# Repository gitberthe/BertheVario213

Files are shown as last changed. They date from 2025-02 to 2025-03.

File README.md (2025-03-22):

# Projet BertheVario213

Projet d'alti vario gps parapente (avec gestion des TMA CTR..., et mode guidage sol pour randonnée).
- Compatible bluetooth / XCTrack si nécessaire.
- Code C++ Visual Studio/PlateformIO.
- Plateforme Espressif ESP32 Dev Module, LILYGO T5 v2.3.1 GDEM0213T5BN 9102 chip, écran 2.13inch DEPG0213BN, Arduino (processeur 32bits, dual core, 240Mhz).

**La carte avec son pcb :**

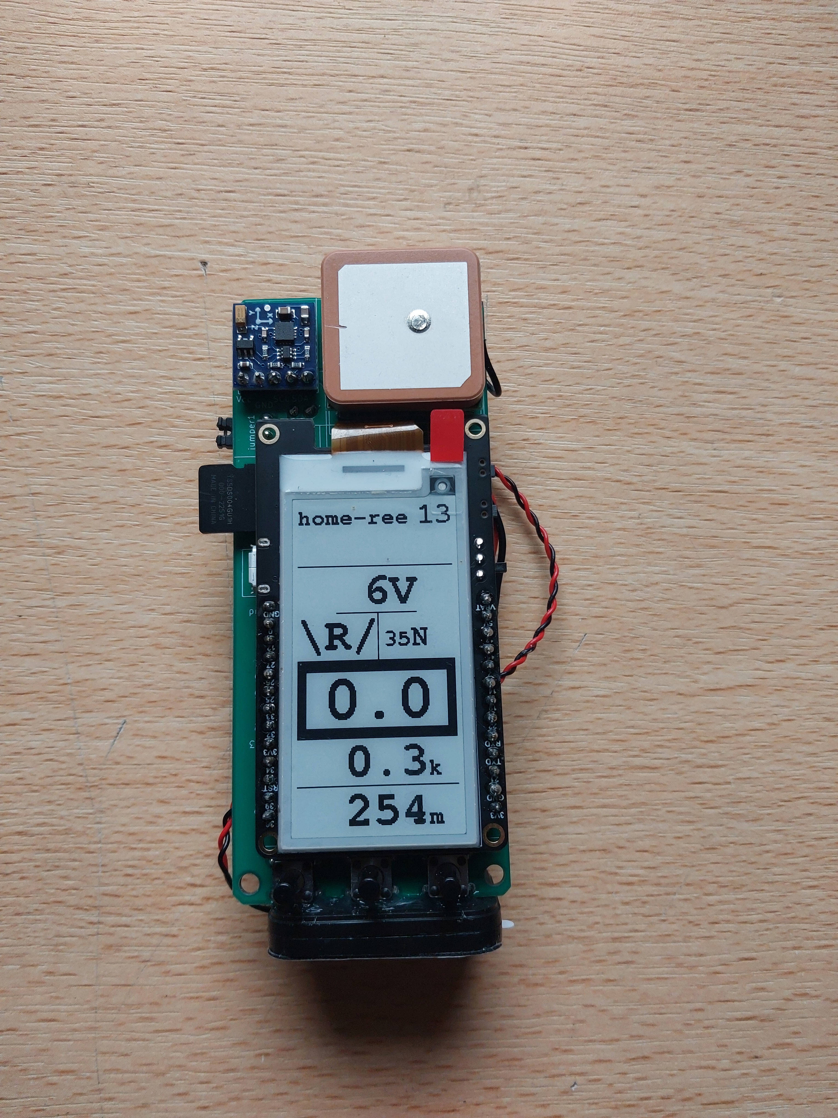
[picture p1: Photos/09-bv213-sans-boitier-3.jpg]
  

**Le schema electrique :**

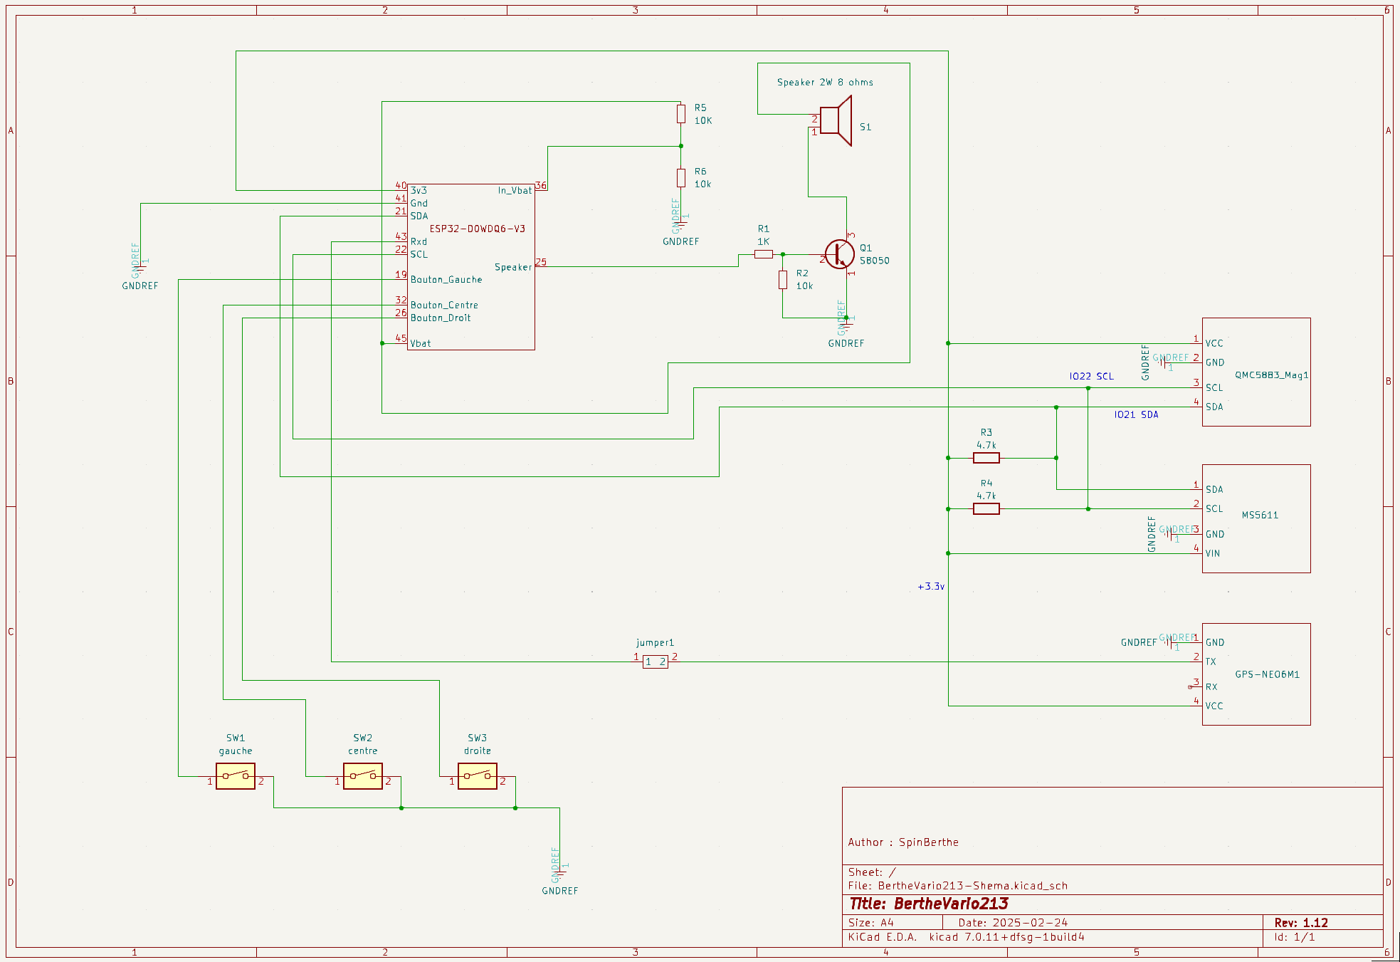
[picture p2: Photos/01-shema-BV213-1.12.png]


**Le pcb :**

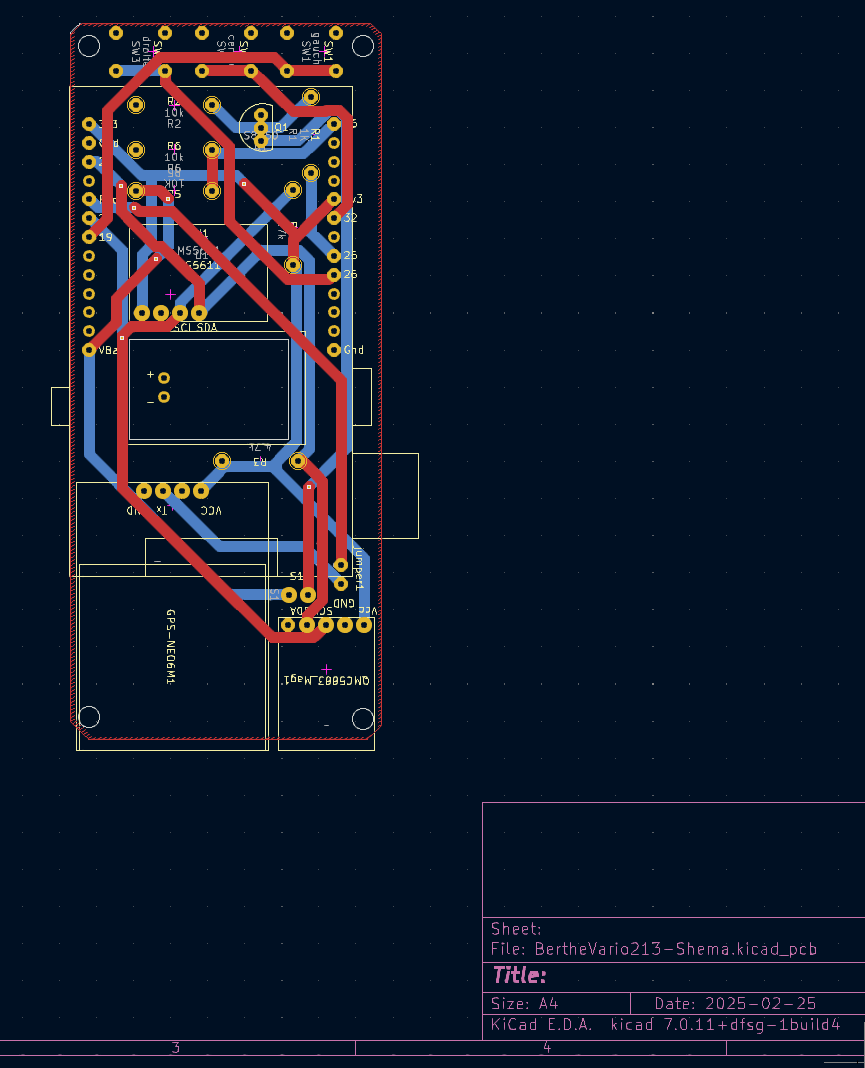
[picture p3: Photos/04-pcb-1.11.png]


**Le mode randonnée :**

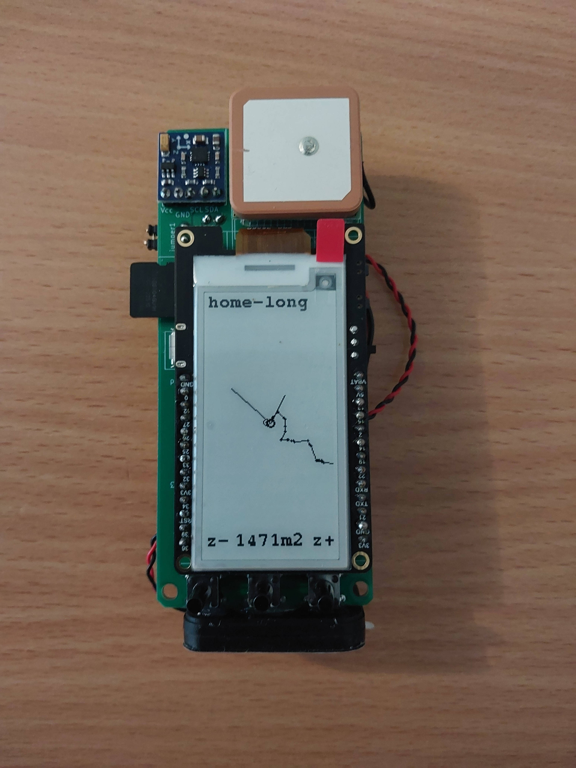
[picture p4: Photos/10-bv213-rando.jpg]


mail: spinberthe@gmail.com

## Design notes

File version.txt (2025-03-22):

le 20250322b :
 - affichage altitude restante/distance/cap de la zone aerienne proche ok.
 - ihm mode randonnee ok.

le 20250322a :
 - emmission message xc_track determiné uniquement par #define XC_TRACK 
 - son vario toujours determiné par [xc_track] == 0 
 - declenchement debut de vol par 2 Vz minimales consecutives. 
 - prise en compte de la hauteur sol pour pre-alarme frontiere XY à Saint-Sandoux.
 - meilleur prise en compte zone st-yan
 - ajout du projet CompZoneAerienne
  
le 20250321c :
 - recadrage caracteres toutes pages.
 
le 20250321b :
 - recadrage caracteres page Sys.

le 20250321a :
 - recadrage caracteres page Vz.

le 20250320d :
 - correction bug bloquage mode ota (firmware wifi).
 - a faire recadrage des caracteres dans les pages.

le 20250320c :
 - quelques modifications de documentation.

le 20250320b :
 - correction bug cap magnetique.
 - ajout vitesse/cap trame RMC Gps (si vitesse faible)

le 20250320a :
 - mode ota ok (firmware wifi).
 - bug cap/vitesse gps trame VTG manquante.
 - bug cap magnetique

le 20250319a :
 - pcb ok. reste a faire le boitier et la mise au point logicielle.

le 20250225c :
 - modif plantage si mauvais zonesper.txt.

le 20250225b :
 - bug periode zone st-yan.

le 20250225a2 :
 - pcb en production mais pas testé.

le 20250225a :
 - modif pcb

le 20250224b :
 - init variables comme vitesse sol gps.
 
le 20250224a :
 - pcb ok a verifier. 

le 20250223a :
 - correction alti baro filtrée.

le 20250222a :
 - mise a jour pcb.
 
le 20250221b :
 - taille caracteres pages.
 
le 20250221a :
 - mise a jour schema/pcb.

le 20250217a4 :
 - modification documentation concepteur.
 - modification pcb

le 20250217a3 :
 - modification pcb.

le 20250217a2 :
 - correction type d'ecran dans documentation.

le 20250217a :
 - progression firmware.

le 20250216a :
 - progression pcb.
 - mise au point son.
 - lecture vbat.

le 20250215a2 :
 - debut conception pcb.

le 20250215a :
 - ajout schema FreeCad et Kicad.
  - rotation ecran.
  
le 20250214b :
 - altitude en bas page Vz.

le 20250214a :
 - ajustement page Vz.

le 20250213c :
 - taille ecran

le 20250213b :
 - reorganisation code

le 20250213a :
 - reception de la lilygo T5 v2.3.1 GDEM0213T5BN 9102 chip, ecran DEPG0213BN :
  . test ecran ok.
  . test carte SD ok.
  . test wifi ok.
  . test ble ok.
 - reste plus qu'a faire tout le reste... gps, boutons, capteur pression, cap magnetique, 
   alimentation, pcb, boitier.
 - l'ecran est tres propre et assez rapide 1/2 image/s.
  
le 20250206a :
 - definition materielle d'un BertheVario ecran 2.13 pouces en cours.

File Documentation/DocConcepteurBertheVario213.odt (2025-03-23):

Documentation Concepteur BertheVario213

Projet d’alti vario gps parapente

à base de

LILYGO T5 v2.3.1 DEPG0213BN 9102 chip

Version 20250322b2

https://github.com/gitberthe/BertheVario213

Compilé avec Visual Studio Code / PlatformIO

Espressif Systems

ESP32 Dev Module

ESP32-D0WDQ6-V3

écran 2.13inch DEPG0213BN

Arduino

langage C++.

spinberthe@gmail.com

# Mise en place de l’environnement logiciel :

Le logiciel est compilé avec Visual Studio Code / PlatformIO.

* La librairie pour le gestionnaire de fichier Wifi doit être modifiée si la version est trop vieille.

Dans BertheVarioTacPlatformIO/.pio/libdeps/esp32dev/ESP32 File Manager for Generation Klick ESPFMfGK/src/ESPFMfGKGa.cpp" ligne 6 : crc32.h => CRC32.h

La compilation du logiciel peut alors s’effectuer.

# Compatibilité XC-Track :

Pour la compilation pour XC-Track voir BertheVarioTac.h et #define XC_TRACK. Ce define consomme de la mémoire. Donc si inutile ne pas le positionner.

Pour supprimer le son du vario, mettre à 0 la variable [xc_track] dans le fichier de configuration (avec le mini éditeur interne).

# Connexion de la batterie :

Connecter la batterie à la carte ESP32 à l’aide du connecteur fournit. Une batterie 4,2v 1S lipo 2000 mah 103450 est suffisante. Elle se recharge par le connecteur usb.

# haut parleur :

Le haut parleur est un haut parleur 2W 8 ohms.

# Téléchargement du firmware :

Pour télécharger le firmware il y a 2 façons :

- soit par câble usb avec platformio ou un autre logiciel. Il faut impérativement retirer le cavalier de la donnée gps pour que le téléchargement se face.

- soit par wifi. Il faut alors mettre le vario en mode téléchargement firmware : page sys, bouton droit long puis gauche court. Et dé-commenter dans platformio.ini les lignes :

; extra_scripts = platformio_upload.py

; upload_protocol = custom

; upload_url = http://192.168.148.237

Avec bien sur l’adresse ip de l’url donnée par l’écran du BertheVario213. Cette procédure ne peut toutefois pas être faite au premier téléchargement de la carte ESP-32. Le logiciel ne s’y trouvant pas, il faut appliquer la procédure USB.

# Quelques photos :

La carte de base ESP32 LILYGO T5 v2.3.1 GDEM0213T5BN 9102 chip avec son écran 2,13 inch DEPG0213BN:

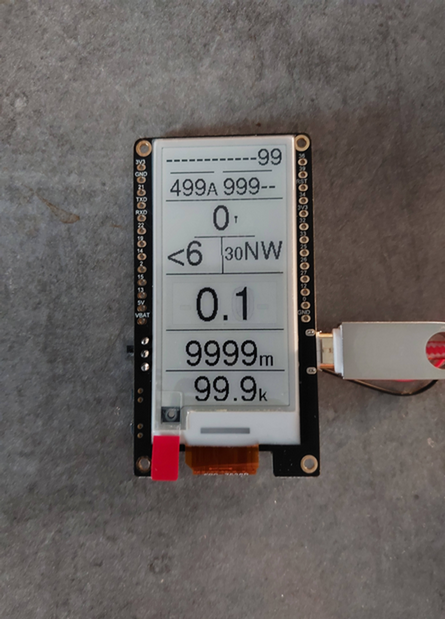
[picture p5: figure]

Attention : Prévoir un film filtre uv car il ne résiste pas au soleil cet écran.

Le circuit imprimé avec ses composants sur les 2 faces. Attention au sens du gps, capteur magnétique, barométrique, et transistor.

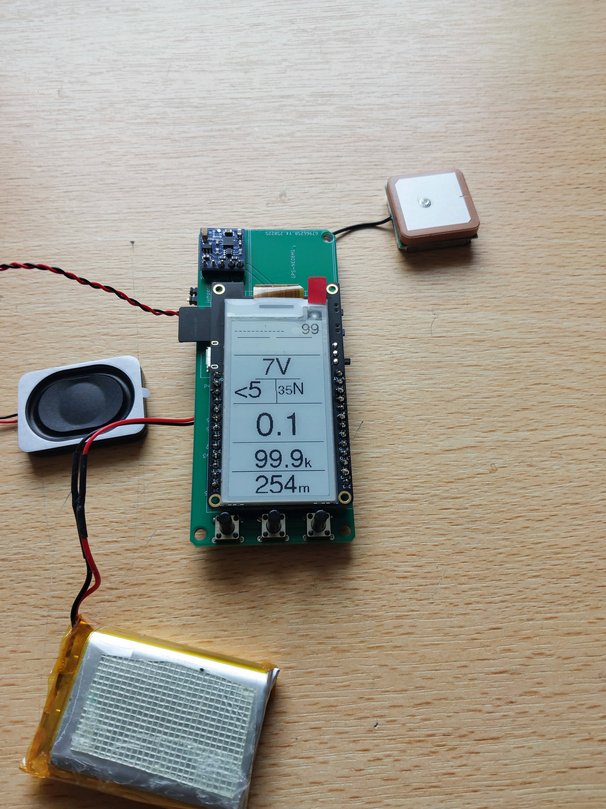
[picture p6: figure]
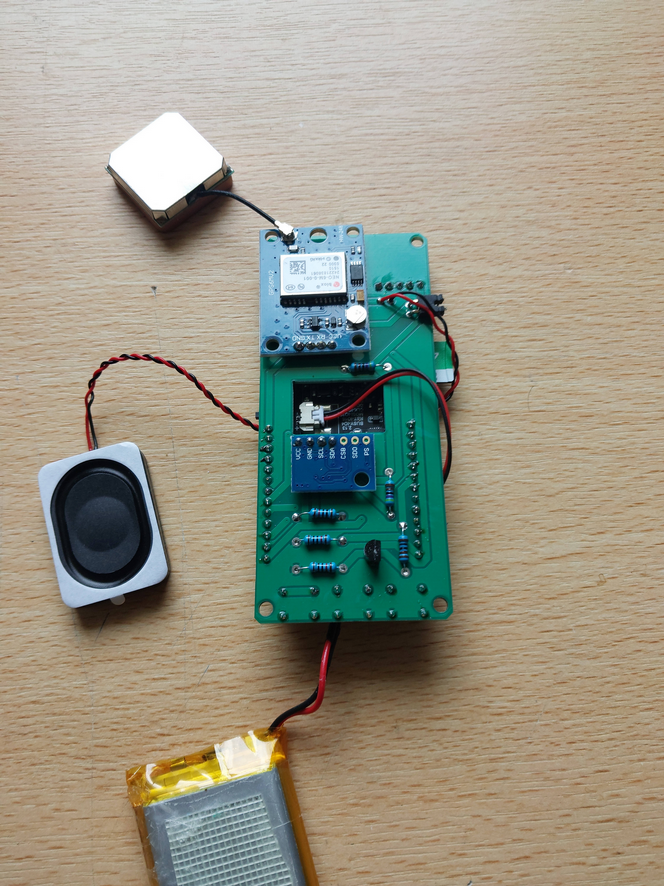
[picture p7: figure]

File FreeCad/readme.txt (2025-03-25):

le 20250325a :
 - conception de boitier en cours.

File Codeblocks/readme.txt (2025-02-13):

- Ce repertoire est present uniquement pour editer/modifier les sources sous codeblocks
- utilisation aussi pour generer la documentation code dans ../../DoxyBertheVario213 : doxygen Doxyfile.BertheVario

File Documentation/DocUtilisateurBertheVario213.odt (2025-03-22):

Documentation Utilisateur BertheVario213

Projet d’alti vario gps parapente

à base de

LILYGO T5 v2.3.1 DEPG0213BN 9102 chip

Version 20250322a

https://github.com/gitberthe/BertheVario213

Compilé avec Visual Studio Code / PlatformIO

Espressif Systems

ESP32 Dev Module

ESP32-D0WDQ6-V3

écran 2.13inch DEPG0213BN

Arduino

langage C++.

spinberthe@gmail.com

Modifications apportées à la documentation :

20250322a: Création documentation utilisateur d’après BertheVario.

# Écran de boot :

A l’écran de boot, il y a possibilité de changer de mode (voir boutons plus bas). Puis il y a affichage de la tension de batterie, du pourcentage batterie et du numéro de firmware.

Une batterie à 4,3v est chargée, à 3,7v vide.

Initialisation du hardware : 1 beep, à la mise sous tension.

Remarque 1 : en mode connexion wifi, les identifiants sont ceux stockés sur la carte SD dans le fichier /config/config.txt.

En mode connexion wifi, il suffit de taper dans un navigateur web http://x.x.x.x:8080 (adresse IP données par l’écran) pour avoir accès à la page téléchargement si dessous (accès au fichiers IGC par clic sur le lien, éditer, renommer. détruire, prévisualiser.)

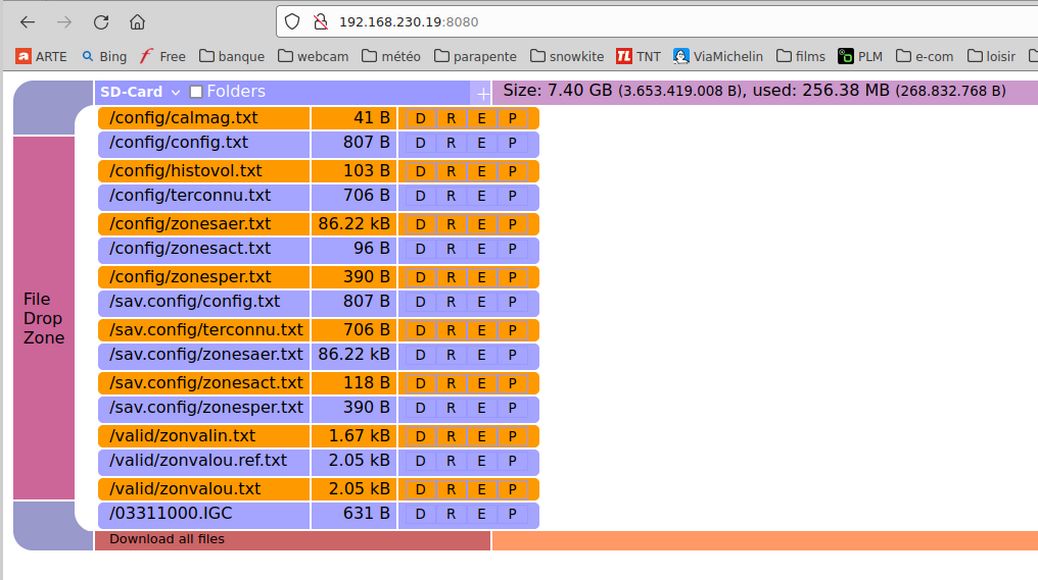
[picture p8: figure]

Remarque 2 : En mode calibration du capteur magnétique. Il faut faire des 8 avec le BertheVario213 jusqu’à re-démarrage (maximum de directions possible dans le sens du cap magnétique).

Il y a mise a jour du fichier /config/calmag.txt sur la carte SD qui est nécessaire au bon fonctionnement du capteur magnétique.

Bien sur, faire des 8 en position à plat ou verticale suivant la configuration firmware “à plat” “ou “suspente gauche ou droite”.

Remarque 3 : si à l’écran de boot, ou lors du fonctionnement normal, on appuie sur le bouton gauche et droit, mais pas sur le bouton centrale, il y a alors reboot du BertheVario213. Utile en cas de faux départ de vol pour redémarrer en mode attente ‘G’/’S’/’V’ sans réinitialiser le GPS (sauf en cas de vol certains, voir plus bas, reboot impossible alors, ce qui évite les fausses manipulations en vol lors de rangement dans les poches etc..).

Boutons :

Gauche : mode calibration.

Central : mode wifi.

Droit : mode rando-vol.

Gauche et droit : reboot.

# Démarrage :

Après le boot et l’initialisation du hardware, il y a démarrage du logiciel et 2 beep. S’il y a 4 beep, c’est qu’il y a un problème de carte SD. Puis il y a affichage de l’écran 0 Vz.

# Écran Vz :

Cap Magnétique

à plat

Nom terrain et finesse

Temps de vol

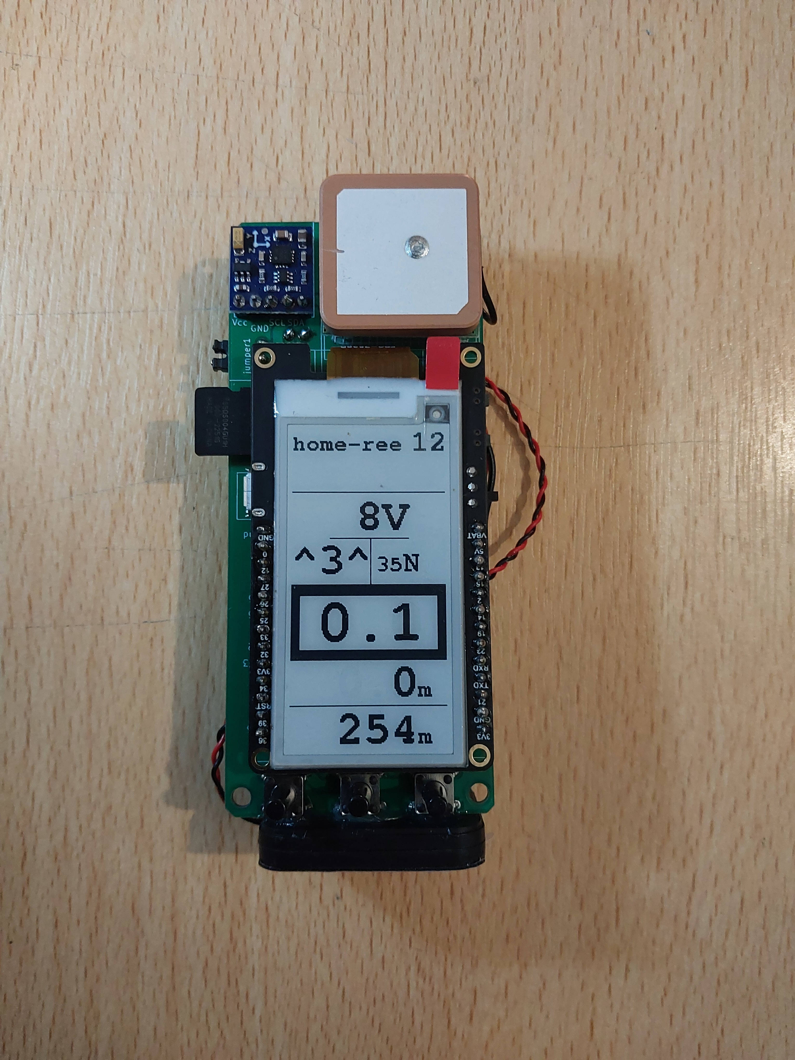
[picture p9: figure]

altitude/distance zone proche

Cap Magnétique

Suspente droite

Cap Sol/Gps

Dérive Sol

Cap Magnétique

Suspente gauche

Vitesse verticale

Altitude

Vitesse/Hauteur Sol

Bouton central

Bouton gauche

Bouton droit

Important : Un appui long sur le bouton centre permet de re-effacer l’écran pour le remettre propre.

Boutons :

- gauche court : activer/désactiver le son d’attente gps G/S/V et/ou alarmes/pré-alarmes pénétration Tma/Zones.

- gauche long : page précédente (bloqué en vol).

- central : page suivante (bloqué en vol).

- central long : raz de l’écran.

- droit court/long: démarrage forcé du vol ( Gps mode S/V) / arrêt du vol ( si < 5kmh et 0,4m/s).

Cap magnétique : le cap est indiqué suivant la direction de la flèche. Il doit avoir été calibré au moins une fois (fichier /config/calmag.txt, voir séquence de boot)

Dérive sol : la dérive sol est indiquée en dizaine de degrés <<4 gauche, 5>> droite ou ^1^ tout droit. \R/ indique une reculade avec alarme sonore désactivable. Gauche indique que l’on dérive a gauche par rapport au cap magnétique.

Nom terrain et finesse / direction et distance du terrain : Indique le nom du terrain d’atterrissage le plus proche et sa finesse pour l’atteindre. Puis par Alternance il y a affichage de ex : 197A 450NE. Qui est la zone TMA/CTR… la plus proche (sauf les zones protégés). Il reste 197 mètres dans ce cas pour atteindre le plafond de la zone sous laquelle on est. Et 450m au nord est pour atteindre une prochaine zone interdite (à l’altitude ou l’on est en ce moment). Apparition à 500m pour l’altitude et 999m pour la distance.

Cap sol : cap issue du gps en dizaine de degrés. Indication Nord, Nord Est ...

Vitesse/Hauteur sol : vitesse issue du gps en km/h. Hauteur sol barométrique en mètres 1sec toutes les 6sec.

Finesse sol : finesse sol issue du gps et du capteur barométrique. Rien si Vz >0, car Vz à la place.

Altitude : Altitude barométrique recalée altitude sol en mètres. Le recalage sol est terminé à la fin de la première stabilisation gps après la mise sous tension. Le gps doit être au sol et pas en vol. Sinon on a l’altitude pression pure et plus la wgs84. On peut donc redémarrer un vol en l’air si nécessaire sans perdre la vraie altitude (ex :stationnarité prolongée en vol qui cause une fin de vol).

Vitesse verticale : vitesse en mètres / secondes, intégrées sur x secondes, filtrées suivant les paramètres du fichier de configuration de la carte SD. Un cerclage noir indique une descente barométrique. Agrandie en si Vz > 0 depuis moins de 10 secondes.

Temps de vol : Temps de vol en minutes.

‘-1G’ indique une attente de données GPS (voyant rouge clignotant) (émission d’un bip toutes les 5 secondes).

‘ 8S’ indique une attente de stabilisation des informations longitude, altitude, 8 satellites en vue (émission d’un bip toutes les 5 secondes).

‘10V’ indique une attente de la vitesse sol importante pour le démarrage de l’enregistrement du fichier IGC de trace GPS, 10 satellites en vue. (émission de 2 bips toutes les 5 secondes)

Les fichier IGC générés sont sous la forme MMJJHHmm.IGC dans la carte SD à la racine au rythme d’un point par seconde.

Émission de 3 beep au démarrage de l’enregistrement IGC.

Pendant la phase ‘G’ ‘S’ et ‘V’ un bip est émit toutes les 5 secondes (suivant G S ou V).

Il peut y avoir arrêt de vol et redémarrage des taches en mode “S” (4 bips) si, pendant 12 secondes:

la position est la même à 30 mètres près, l’altitude pression à +-3m, la vitesse n’est pas supérieur à 5km/h ou 0,4m/s.

Et si l’altitude n’est pas supérieur à celle du décollage +5m.

Il y a aussi arrêt du vol si on appui sur la touche droite avec une vitesse inférieur à 5km/h et 0,4m/s.

De plus si l’on à été à plus de 400m ou 3m d’altitude, il y a alors vol certains, et reboot par les touches GD impossible.

De même le reboot est impossible si la vitesse sol Gps est > 5km/h.

Lors du changement du nombre de satellites en vue, le déclenchement de vol par vitesse est interdite pendant x secondes (imprécision/recalage position).

Nom terrain et finesse : Conformément au fichier “/config/terconnu.txt” de la carte SD. Affichage du terrain accessible avec la plus petite finesse. Et affichage de la finesse pour l’atteindre.

Remarque 1 : Il y affichage de la TMA/CTR/Zone protégé pénétré (avec son altitude) à la place du nom terrain finesse si l’on est dedans ou proche (voir fichier /config/zonesaer.txt). (2 bips si dans la zone, 1 bip si limite frontière ou altitude).

Bo R 368 B al:0m indique que l’on est en “border” en bordure XY de la R 368 B qui commence a une altitude de 0m, zone active.

Be TMA 5.1 al:3500m indique que l’on est en “below” en dessous de la TMA 5.1 qui commence a une altitude de 3500m ce jour.

In TMA 2.3 al:1980m indique que l’on est en “in” on a pénétré la TMA 2.3 qui commence a une altitude de 1980m.

Al TMA 5 al:2590m indique que l’on est proche de “altitude” l’altitude de la TMA 5 qui commence a une altitude de 2590m.

Zp PROTECT Reserve naturelle al: 0m indique que l’on a pénétré une zone protège (en dessous de 1000/ … /50m sol).

Al PROTECT Reserve naturelle al: 0m indique que l’on survole une zone protégé en dessous de la marge d’altitude (en dessous de 1000/500/300/150/50m sol + marge altitude).

Remarque 2 :On peut déclencher un début de vol par le bouton droit en écran Vz (sans stabilisation gps). On peut arrêter un vol aussi par le bouton droit si la vitesse sol est < 5kmh et la Vz < 0,4m/s.

# Voyants LED / interrupteurs / carte SD:

A droite des 3 boutons, il y a une led de couleur rouge qui clignote quand le GPS est accroché et valide.

En charge, il y a une led bleu qui s’allume vers l’interrupteur marche/arrêt de gauche.

A coté de l’interrupteur marche/arrêt, il y a la carte SD.

# Écran Histo:

On accède à l’écran Histo par un appui sur le bouton centre âpres l écran Vz. L’écran revient à l’écran Vz au bout de 15 secondes.

L’écran 1 contient le nom du fichier Igc, la Z décollage, la Z max, la Vz Max, la Vz Min, la distance parcourue, la Vs Max et le temps total du vol. Ces informations sont issues des fichiers “/histo/nom_igc.his”.

Boutons :

- gauche long : page précédente.

- central : page suivante.

- central long : raz de l’écran (attention par temps froid).

# Écran Affichage / Archivage IGC :

Ces 2 écrans entre les écrans historique du dernier vol et gestion des TMA permettent :

- pour l’écran affichage igc, affichage des temps des fichiers IGC sur la carte SD et calcul de leur total en minutes decimale (si vol supérieur à 30 secondes). Attention si le vent est fort de face et que le départ est lent, le vol risque de ne pas déclencher (3 bips de début de vols émit en l’air).

- pour l’écran archivage (bouton gauche/droite, permet d’archiver tous les fichiers IGC de la carte qui sont à la racine. Dans le répertoire /arch/annee. Destruction des vols < 1 min.

Beeper

Antenne Gps

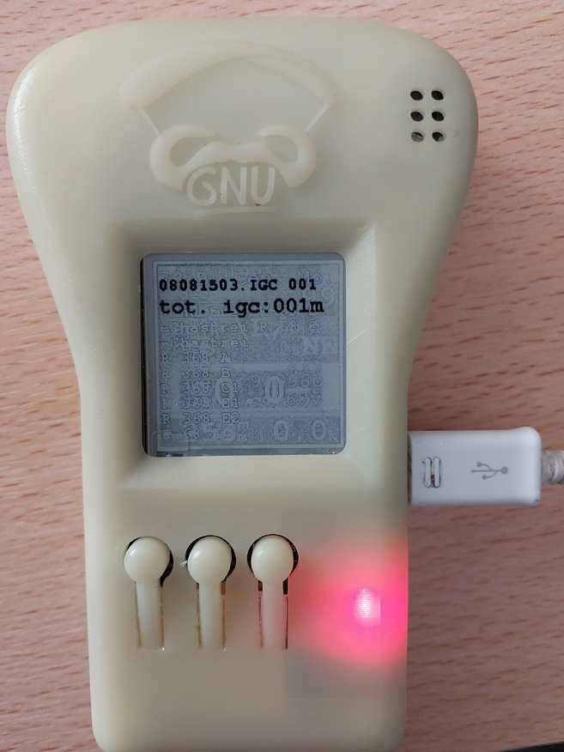
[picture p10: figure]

LED bleue de mise en charge, interrupteur M/A, carte SD

LED Gps rouge

Boutons :

- gauche long : page précédente.

- central : page suivante.

- central long : raz de l’écran (attention par temps froid).

- gauche/droit : archivage fichier igc. (central annulation)

# Écran Zone Aériennes / Modification :

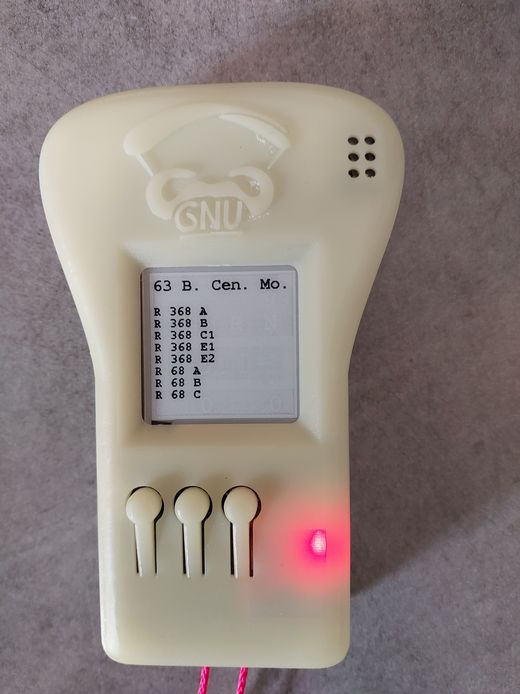
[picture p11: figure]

On accède à l’écran zone aériennes par un appui sur le bouton centre depuis histo. L’écran revient à l’écran 0 au bout de 15 secondes. Cet écran est pour la gestion des zones aériennes. On a le nombre de zones aériennes en mémoire, ainsi que le nom des zones modifiables activées ou “–Nom“ si désactivée.

Depuis l’écran zone aérienne, avec un clic droit/gauche on passe à l’écran modification pour lire ou modifier l’activation des zones. L’écran revient à l’écran Vz au bout de 15 secondes. Les boutons gauche/droit font défiler les zones, le bouton centrale peut modifier l’activation de la zone en cour (si elle est mod et pas const).

Il y a affichage à l’écran modification des informations nom, activation modifiable (mod) ou figée (const), altitude basse hors période, période début JJ-MM, période fin JJ-MM, altitude basse période semaine, altitude basse période week-end. Si la zone est « protect » ou « ffvl-prot », affichage de la hauteur sol minimale de survole (ex : Chastreix, Chaudefour, Parc des Cevennes, Gypaete barbu...)

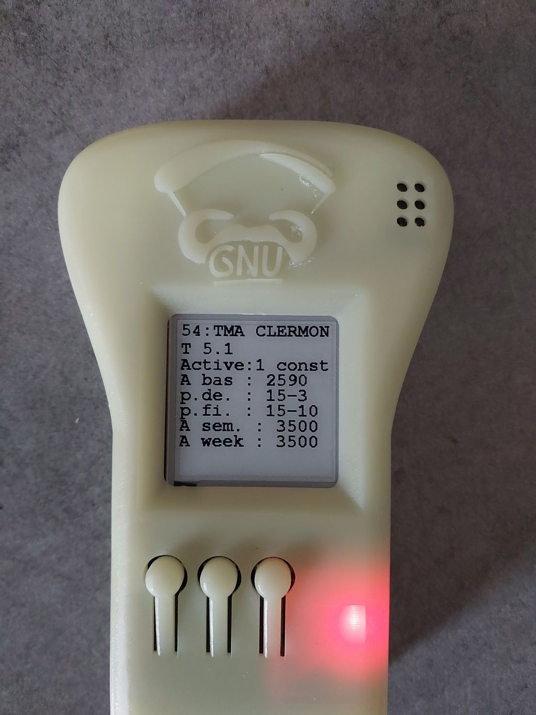
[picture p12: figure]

Boutons :

- gauche long : page précédente.

- central : page suivante. si mode navigation zone : activation/désactivation Tma/Zone

- central long : raz de l’écran (attention par temps froid).

- gauche/droite : mode navigation dans Tma/Zone et retour page Tma global.

- long G/D début/fin Tma/Zones si mode navigation Tma/Zone.

La modification de l’activation de la zone est mémorisée dans le fichier /config/zonesact.txt. Et seul les zones présente dans ce fichier sont modifiable. Le format est : nom_zone;0;. Il faut donc le générer une première fois avec un éditeur de texte, pour pouvoir le modifier par la suite.

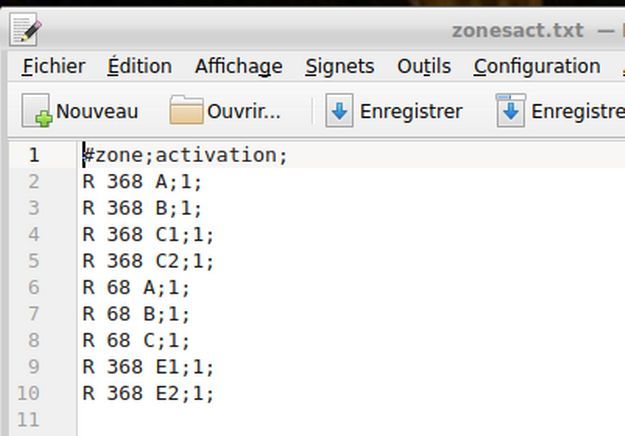
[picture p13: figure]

Remarque :

Les zones ne figurant pas dans ce fichier sont considérées comme toujours actives.

La totalité des zones sont dans le fichier /config/zonesaer.txt, voir plus bas pour le générer.

La configuration des périodes est dans le fichier /config/zonesper.txt. Il est de la forme :

nom zone;nom affichage;début période;fin période;alti semaine;alti week-end

ex : TMA CLERMONT 2.1;TMA CFD 2;15-03;15-10;1980;1980

Nom zone est le nom dans le fichier /config/zonesaer.txt, les 3 premiers champs. Nom affichage est le nom de remplacement à l’affichage, puis JJ-MM début période, JJ-MM fin de période, altitude période semaine, altitude période week-end.

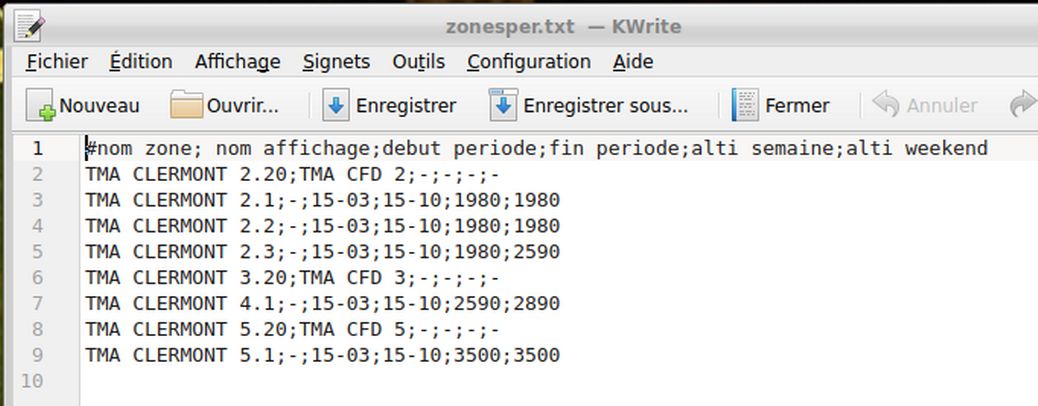
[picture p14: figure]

# Écran Éditeur Configuration:

On accède à l’écran éditeur par un appui sur le bouton centre après l’écran TMA. On a alors accès a un mini éditeur du fichier de configuration. On peut ainsi modifier les variable par bouton central, puis G/D pour incrémenter / décrémenter. Ex 1: [dtu] => augmentation/diminution de 1 avec les boutons. Ex 2 : [vz_seuil_haut] => augmentation/diminution de 0,05 avec les boutons C/G/D. Les modifications sont automatiquement pris en compte et sauvegardées dans le fichier de configuration /config/config.txt dès le retour à une autre page. S’il n’y avait pas de fichier, un fichier par défaut est créé.

Boutons :

- gauche long : page précédente.

- central : page suivante. si mode navigation variables : mode modification/navigation variable.

- central long : raz de l’écran (attention par temps froid).

- gauche/droite : navigation dans variable et sortie de navigation variable. Incrémentation/décrémentation variable si mode modification.

- long G/D début/fin variable si mode navigation variable.

# Écran Tma Dessous:

On accède à l’écran Tma dessous par un appui sur le bouton centre après l’écran éditeur. On a alors accès à la Tma sous laquelle on est, avec son altitude. Ainsi que les coordonnées du point gps en cours.

Boutons :

- gauche long : page précédente.

- central : page suivante. Annulation mémorisation point.

- central long : raz de l’écran (attention par temps froid).

- gauche/droite : mémorisation point courant dans le fichier des terrains connus. Exemple : mémoriser un nouveau terrain d’atterrissage.

# Écran Système :

On accède à l’écran système par un appui sur le bouton centre âpres l’écran Tma dessous. L’écran revient à l’écran Vz au bout de 15 secondes. Cet écran est plus informations système avec date et heure, cap magnétique, pourcentage d’utilisation core 0 et 1, température à l’intérieur du boîtier, mémoire libre en octets, tension batterie, et numéro du firmware. Pour info, une zone aérienne prend de 1 à quelques ko suivant sa taille. Il y a donc de la marge dans le cas ci-dessous.

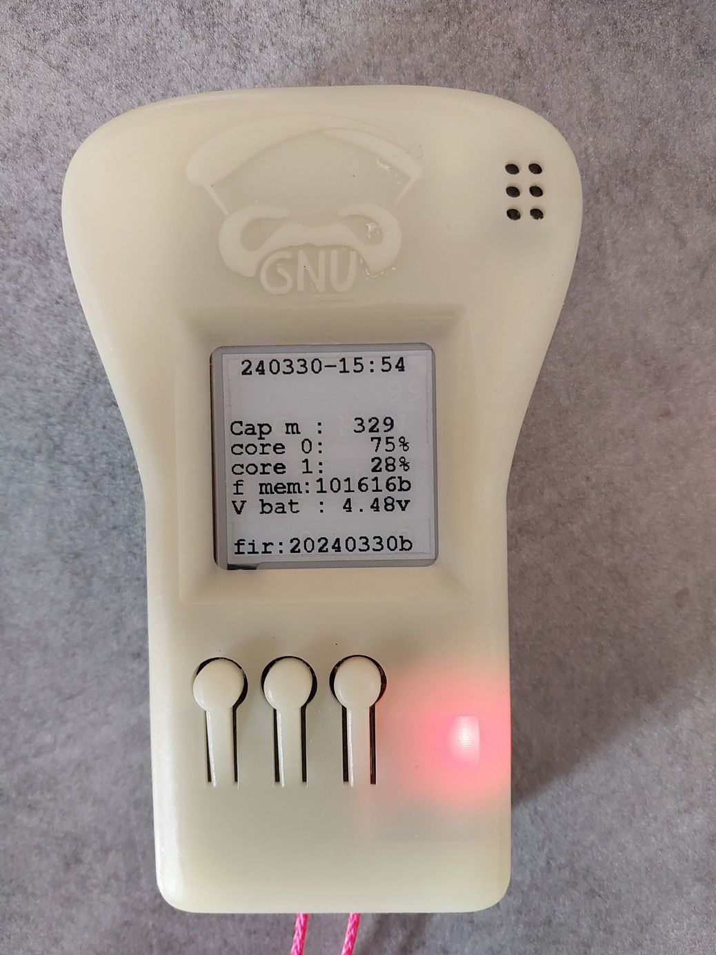
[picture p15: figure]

Boutons :

- gauche long : page précédente.

- central : page suivante.

# Fichier de configuration SDCard/config/config.txt :

Le fichier de configuration doit être placé dans le dossier /config a la racine de la carte SD. La carte SD contient aussi les fichier IGC générés par un vol (ou un faux vol de 12 secondes).

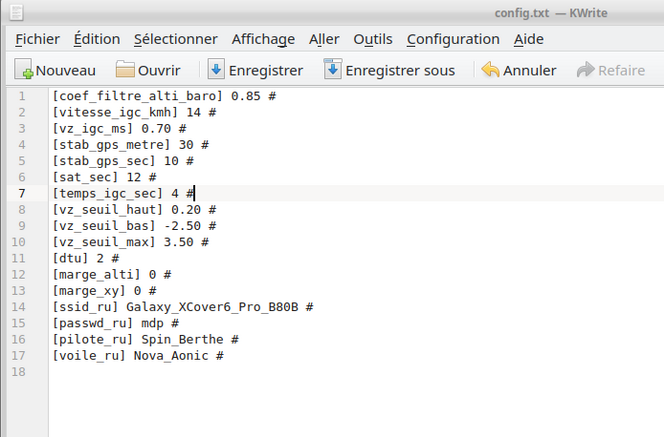
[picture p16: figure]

Compléter les informations nécessaires dans ce fichier. Les # sont des commentaires, pour le mot de passe, ssid, pilote et voile les ‘_’ sont remplacés par des blancs/espaces.

Le fichier est généré automatiquement si vous passer une fois en page mini éditeur s’il n’existait pas auparavant avec les valeurs par défaut.

[coef_filtre_alti_baro] : filtrage alti baro, valeur [0,1[, 0.999 donne un très grand filtrage mais un léger retard dans la valeur. 0. ne filtre rien et donne par conséquent des beep intempestifs. Mettre 0.85 pour un filtrage correct.

[xc_track] : A false par défaut. Si à true désactive alors le son vario uniquement. Voir le #define XC_TRACK (lors de la compilation) dans BertheVario.h. Cette fonctionnalité consomme 40ko de mémoire !!!

[vitesse_igc_kmh] : vitesse sol de déclenchement de l’enregistrement. Début de vol déclenché au bout de temps_igc_sec secondes de vitesse successive supérieur à (14km/h par défaut). S’il y a faux départs de vols cause imprécision gps, ne pas bouger le temps de la détection de stationnarité (quelques secondes). Il y a alors redémarrage des taches automatiquement en mode S/V.

[sat_sec] : temps en secondes d’interdiction de départ de vol lors du changement du nombre de satellites en vue (cause d’imprécision position/vitesse) (12 sec par défaut pour 4 satellites, puis 0 pour 30 satellites).

[temps_igc_sec] : nombre de secondes ou la vitesse igc doit être atteinte pour déclencher un vol (4s par défaut).

[vz_igc_ms] : + ou - vitesse verticale pour déclencher un vol (0,5 par défaut, 2 consécutives).

[stab_gps_metre] : rayon de dispersion des points gps, en mètres, à ne pas dépasser pour considérer le Gps stable. Le gps met parfois 1 à 2 minutes pour se stabiliser. Il est donc recommandé de mettre le GnuVario sous tension pendant la pre-vol (30m par défaut).

[stab_gps_sec] : taille de la pile en secondes pour le calcul de la stabilisation gps (10 sec par défaut)

[vz_seuil_haut] : Vz ascendante de déclenchement des beeps aiguës (0,2 par défaut).

[vz_seuil_bas] : Vz descendante de déclenchement des beeps grave (-2,5 par défaut).

[vz_seuil_max] : Vz ascendante des beep vario maximum très aiguës (4 par défaut).

[ssid_ru] : nom wifi pour téléchargement des IGC via navigateur web. (underscores remplacés par des espaces)

[alarme_reculade] : activation alarme sonore reculade (désactive par défaut).

[dtu] : heure a ajouter a l’heure gps pour le nom des fichiers *.igc.

[marge_alti] : marge en altitude mètres pour près alarme pénétration zone TMA/CTR. (Rappel : altitude barométrique recalée altitude sol phase S)

[marge_xy] : marge en XY, distance en mètres pour près alarme pénétration zone TMA/CTR. Distance par rapport à sa frontière dans le plan horizontal.

[passwd_ru] : mot de passe wifi (underscores remplacés par des espaces)

[pilote_ru] : nom de pilote dans le fichier igc (underscores remplacés par des espaces)

[voile_ru] : nom de voile dans le fichier igc (underscores remplacés par des espaces)

# Fichier de terrains connus SDCard/config/terconnu.txt :

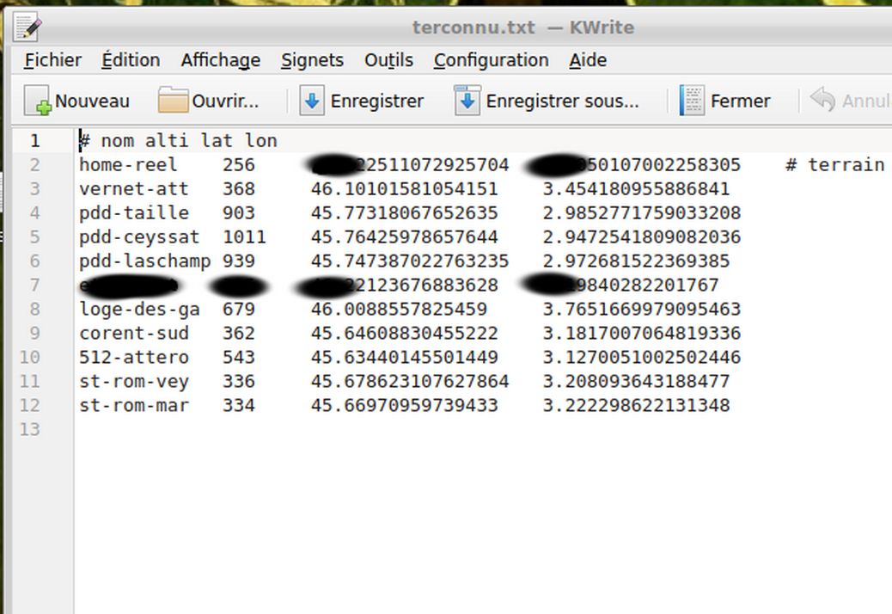
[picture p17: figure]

Comme vous pouvez le voir, ce fichier liste les terrains connus avec leur nom de 10 caractères maximum ainsi que leur coordonnes. Utile pour avoir la finesse du terrain le plus proche. Et pour générer les zones aériennes autour de ces points.

# Fichier de calibration SDCard/config/calmag.txt :

Ce fichier est généré automatiquement par appuis au boot sur le bouton gauche. Faire des 8 avec le boîtier jusqu’au redémarrage pour calibrer le capteur magnétique.

# Fichier d’historique de vol SDCard/config/histovol.txt :

Ce fichier est généré automatiquement à chaque nouveau vol. Il est lu pour afficher l’écran 1. Sa forme est la même que celle dur fichier “/config/config.txt”.

# Fichier IGC :

Les fichier IGC sont téléchargeable en mode wifi (voir séquence de boot) et peuvent être visualisés sur le web avec https://e-logbook.org par exemple. Ils contiennent les date et position pour chaque seconde. L’altitude GPS qui est fausse a 50m près souvent, c’est pour cela que je ne la met plus. Il contient aussi l’altitude barométrique qui est recalée altitude sol pendant la phase S stabilisation (il est donc important de laisser le vario au sol pendant cette phase). Cette dernière est assez précise (10cm normalement) pour peut que l’on ai laissé le GPS immobile pendant la phase S, le temps qu’il se cale bien en lat/lon pour extraire la bonne altitude des fichier *.hgt. On a alors un fichier IGC précis à quelques mètres. Que l’on peut convertir en kml avec http://meles.work/igc/igc.html.

# Carte SD :

La carte SD doit etre formaté en fat16/fat32 les fichiers “/config/terconnu.txt”, “/config/config.txt”, “/config/calmag.txt”, “/config/zonesaer.txt”, “/config/zonesact.txt” et “/config/zonesper.txt”. Et les fichiers generes “/config/calmag.txt” et “/histo/nom_igc.his”. Les fichiers *.IGC sont créées à la racine.

Elle contient aussi les fichiers de validation de zone “/valid/zonvalin.txt” et le fichier généré au boot wifi “/valid/zonvalout.txt”.

Important : Pensez a installer aussi les fichier de hauteur sol *.hgt, pour toute la france, dans le repertoire "/config/hgtdata". Ceci est obligatoire car il y a recalage d’altitude barométrique avec ces fichiers avant le decollage ( https://www.viewfinderpanoramas.org/Coverage%20map%20viewfinderpanoramas_org3.htm ).

# Rechargement du GnuVario :

Utiliser un cable micro-usb. Une lumière bleue doit être visible par les interstices du boîtier. Une recharge complète prend plusieurs heures. La tension de la batterie doit être à 4,6/4,7v en pleine charge (3,7v déchargée)(c’est un peut faux pour une lipo, mais le pont de résistances est ainsi). La tension de la batterie est affichée a l’écran de boot ou en page sys.

# Le Gps :

Bien entendu le Gps accroche mieux en pleine nature qu’en ville, en terrain découvert que sous les arbres, par ciel clair que pluvieux, à l’arrêt qu’en déplacement. Attendre le clignotement de la LED rouge et l’affichage d’une altitude cohérente à l’écran avant de faire le vol (recalage altitude barométrique par altitude sol jusqu’au début du vol).

# Les zones aériennes et le fichier SDCard/config/zonesaer.txt :

Les zones aériennes qui sont traversées sont affichées en lieux et place de “terrain connu accessible”. Si l’on traverse une zone aérienne, il y a affichage du nom de la zone ainsi de que sont altitude minimale avec une alarme sonore (l’altitude est fonction de la zone, de la date en ou hors périodes, et de la semaine ou du week-end dans la période). L’alarme sonore est activable/désactivable par le bouton du milieu.

Peut de zones tiennent en mémoire du GnuVario. Donc, pour ce faire, il faut prendre le fichier PlatformIO/Projects/CompZoneAerienne/data/20240615_ffvl-cfd.geojson (disponible sur le net, fichier generer par “Pascal Bazile” http://pascal.bazile.free.fr/paraglidingFolder/divers/GPS/OpenAir-Format/download.php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 ) et le découper avec le programme PlatformIO/Projects/CompZoneAerienne/CompZoneAerienne qui compresse les zones à fort nombre de points (itération 3 points distance à la droite < 4,5 mètres) ..

Utilisation : CompZoneAerienne lat_centre_deg lon_centre_deg rayon_km > zonesaert.txt. Ou CompZoneAerienne –batch terconnu.txt rayon_km > zonesaert.txt pour utilisation du fichier des terrains connus. Le programme enregistre alors dans le fichier toutes les zones coupant les cercles définit par leur centres et rayons des points connus. Il suffit de placer ce fichier sur la carte SD/config.

Attention : Si le fichier est trop gros, il plante le GnuVario au boot lors de sa lecture. C’est pour cela qu’il y a des zones réduites en nombre de points par CompZoneAerienne, Ceci est fait lors de la génération du fichier. Comme pour les zones protégées “PROTECT” qui ont un énorme nombre de points de définition (1800 pour Chaudefour)(Validation Gnuplot très acceptable). L’algorithme utilisé est la suppression des points proches d’une droite.

De plus, pour gagner en mémoire il y a un algorithme de compression de données de float 32bits vers short 16bits dans le firmware. Les zones ont ainsi une résolution variable de 1 à 7 mètres par rapport aux zones du fichier. En moyenne la résolution est de 1,95metres. Si il y a un problème de compression short il y a beep et reboot.

Remarque : Les fichiers *.hgt nécessaire au calcul de la hauteur sol sont a mettre dans le répertoire “SdCard/config/hgtdata” (à télécharger sur https://www.viewfinderpanoramas.org/Coverage%20map%20viewfinderpanoramas_org3.htm). Il y a test de présence au démarrage du centre de la France.

Important : Le GnuVario a été activement teste pour différent sites d‘Auvergne, a différentes périodes, altitudes et marges XY Z. Je décline toutes responsabilité quand à sa fiabilité à ce sujet (on est jamais à l’abri d’un oubli dans l’algorithme), en Auvergne et encore moins dans une autre région. Les zones étant bien imbriquées, vérifier par procédure de test, au moins un point par zone, que le comportement est correct chez vous. Pour cela il y a 2 façons :

- Rappel : dans la page “histo ecran 1”, la zone et le plafond courant sont affichés.

- Utiliser le fichier /valid/zonevalin.txt de la carte Sd. Puis booter en wifi. Il y a alors génération de /valid/zonevalou.txt avec les résultats.

Zonevalin.txt est de la forme :

#ville;lon,lat;annee,mois,jour;altitude,marge_xy,marge_z;zone a_active,zone_b_active;

Zonevalou.txt est de la forme :

numéro_ligne;ville;date;TMA;altitude_plafond;alarme_générée;

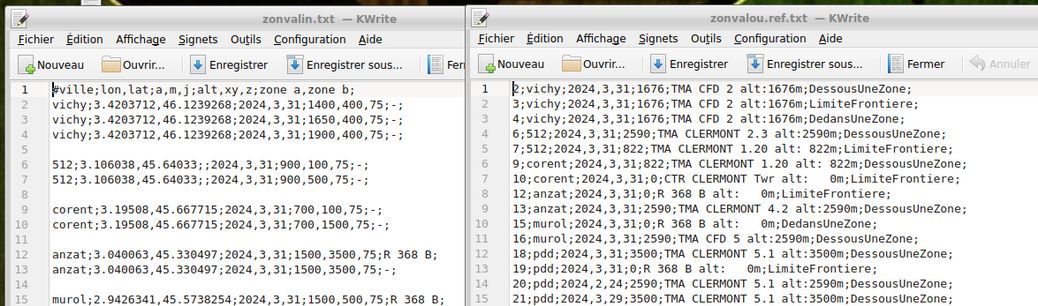
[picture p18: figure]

Remarque :

Il y a un fichier généré en mode wifi /valid/zonomout.txt qui donne la correspondance des noms de zones du fichier json => nom interne GnuVario. Utile pour renseigner le fichier des zones activables /config/zonesact.txt.

# Pour les développeur qui veulent recompiler :

Pour ceux qui veulent recompiler le programme pour leur écran ou autre. Installer Visual studio code sur linux (ou Windows) comme préconiser sur https://prunkdump.github.io/GNUVario-TTGO-T5-website/code/ide_platformio.html (avec plateforme IO et board espressif ESP32 Dev module).

Copier les dossiers de https://github.com/gitberthe/BertheVario dans ~/Documents/PlatformIO/Projets.

Ouvrir le projet BertheVarioPlatformIO. Modifier les fichiers désirer, et en particulier les // commentaires des ecrans dans les fichier *.h du repertoire Screen sections ESP32. Ou les “#define GNU_VARIO_GRIS” dans BertheVario/src/BertheVario.h et ses différents #define DEBUG_XYZ.

Puis compiler/uploader le firmware (petite fleche en bas à gauche de VSCode, port /dev/ttyACM0 sous linux) de préférence sans la carte SD. Ca reboot automatiquement le GnuVario.

Débogage par “Moniteur Serie”.

Important : la librairie du capteur magnétique Mpu9250 a été modifiée pour la lecture a 5hz sinon sa plante le capteur, donc attention si vous la réinstallée (apparemment avec github et pull):

- modifier "/BertheVarioPlatformIO/.pio/libdeps/esp32dev/MPU9250/MPU9250.h" ligne 85 : 0x06 en 0x02.

- modifier aussi "BertheVarioPlatformIO/.pio/libdeps/esp32dev/ESP32 File Manager for Generation Klick ESPFMfGK/src/ESPFMfGKGa.cpp" ligne 6 : #include <crc32.h> en <CRC32.h>.

Remarque : Pour ceux qui utilisait le GnuVario firmware d’origine et veulent toujours l’utiliser. Je leur conseil de rajouter un mutex entre le son et les différents capteurs, ça ne gêne en rien le fonctionnement dans le programme. Mais ça évite qu’il plante et reboot aléatoirement dans les ascendances, ou ça bip, au bout d’une demie heure.

Rappel : Pour ceux qui veulent recompiler CompZoneAerienne et ainsi générer leur propre zones, le faire sous codeblocks, aussi bien sous windows que sous liux.

Pour windows voir le programme et ses .dll déjà compilées dans le dépôt https://github.com/gitberthe/BertheVario

# Le mode randonnée pour ne plus se perdre :

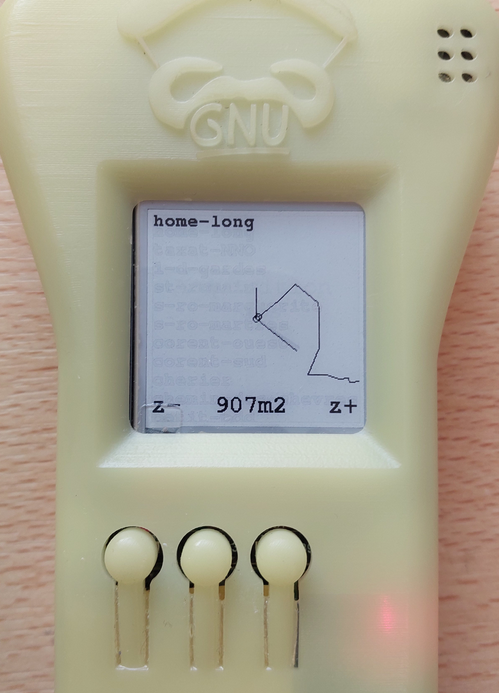
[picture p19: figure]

Trace du fichier Gpx

Echelle de la carte

Nom trace courante

Zoom + et -

Nord magnetique

Cap Gps

Position courante

Le mode randonnée est un mode de guidage terrestre pour rejoindre un décollage inconnu par exemple.

Il est accessible au boot par l’appui sur le bouton droit (rappel : gauche calibration magnétique, centre filemanager wifi, gauche et droite reboot).

Au démarrage, il y a acquisition du Gps. Puis une fois le Gps fonctionnant, il y a lecture des fichiers *.GPX du répertoire /SdCard/Gpx, ainsi que du fichier des terrains connus et d’un fichier similaire ptremarq.txt. Et affichage quelques secondes des traces/points les plus proches (rappel on peut télécharger les fichiers par wifi, drag&drop).

Suivant la position Gps, la trace/point gpx la plus proche est chargée en mémoire au bout de quelques secondes. On peut sélectionner une autre trace par les boutons gauche/droite/centre. Le guidage alors commence.

A l’écran on a :

- Le nom de la trace du fichier gpx (8 caractères maximum + 3 pour l’extension). Le nom de la trace est celui dans le fichier (la balise <name>) et peut être modifiée avec un éditeur de texte standard.

- La grande ligne est le nord magnétique issu du capteur magnétique (qui doit être calibré bien sur). Dans mon cas le haut du GnuVario mais ça dépend de la compilation (fichier BerheVario.h #define VARIO_CAP_MAG_A_PLAT 1 2 ou 3).

- La trace gpx, orientée au nord, à l’échelle indiquée en mètres carrés pour la surface de l’écran.

- Les touches gauche/droite pour zoom fois 2, divisé par 2.

- le centre de l’écran est la position actuelle.

- La petite ligne est le cap gps.

Donc en alignant le nord magnétique en haut de la carte on peut se situer par rapport à la trace. Le petit rond de la trace indique le début de la trace. Pour ma part c’est souvent l’atterrissage.

On peut aussi mettre la ligne du cap gps en direction de la trace pour la rejoindre. Ou parallèle à la trace pour la suivre.

D’autre part, avec le bouton centre, on affiche la page informations pour quelques secondes. Avec les distances/altitudes positive faites et restantes.

On peut aussi orienter la carte au cap gps lors de la marche (boutons long G/D ou double appui).

Je crée souvent les traces avec https://www.visugpx.com/editgpx.

Boutons :

Centre : validation trace si menu. page info rando si mode trace.

Centre long : raz écran.

Gauche/Droite : sélection trace si menu. Zoom+/-.

Gauche/Droite long : cap nord/gps.

A vos bâtons de marche...

Merci aux premiers concepteurs du GnuVario

et

Bon vols.

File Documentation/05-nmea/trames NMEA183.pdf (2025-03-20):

# Les Trames NMEA

### 1 - Présentation

NMEA - National Marine & Electronics Association, est une Association à but non lucratif fondée par un groupement de professionnels de l'industrie de l'électronique des périphériques marine, conjointement avec des fabricants, des distributeurs, des revendeurs, des institutions d'enseignements. Leur but entre autre, harmoniser et standardiser les équipements de la marine.

NMEA est à l'origine de nombreux standards et en particulier du Standard NMEA-0183.
Dans ce qui suit, le Standard NMEA est défini "simplement" et uniquement comme étant le protocole de transmission des données entre les instruments et équipements électroniques liés au GPS.

### 2 - DEFINITION DU STANDARD NMEA-0183

Sous ce standard, toutes les données sont transmises sous la forme des caractères ASCII, tous imprimables, ainsi que les caractères [CR] Retour Chariot et [LF] Retour à la ligne, à la vitesse de transmission de 4800 bauds.

Les données sont transmises sous forme de trames (sentences, phrases).

Chaque trame commence par le caractère $

Suivi par un groupe de 2 lettres pour l'identifiant du récepteur. (Non limitatif):

- GP pour Global Positioning System.
- LC Loran-C receiver.
- OM Omega Navigation receiver.
- II Integrated Instrumentation (eg. AutoHelm Seatalk system).

Puis un groupe de 3 lettres pour l'identifiant de la trame.

- GGA : pour GPS Fix et Date.
- GLL : pour Positionnement Géographique Longitude - Latitude.
- GSA : pour DOP et satellites actifs.
- GSV : pour Satellites visibles.
- VTG : pour Direction (cap) et vitesse de déplacement (en noeuds et Km/h).
- RMC: pour données minimales exploitables spécifiques.

Suivent ensuite un certain nombre de champs séparés par une "virgule". Le rôle de la virgule est d'être le séparateur de champs, qui permet la dé-concaténation des données dans le programme de traitement des données, calculateur, navigateur.

Et enfin un champs optionnel dit checksum précédé du signe *, qui représente le OR exclusif de tous les caractères compris entre $ et * (sauf les bornes $ et *), certaines trames exigent le checksum.

Suit la fermeture de la séquence avec un [CR][LF].

Un total de 82 caractères maximum pour une trame.

Et on passe à la trame suivante.

Les trames NMEA | BAC PRO SEN EIE | LP du Giennois | page : 1

### 3 -La trame : GGA

Données d'acquisition du FIX – GPS.

### $GPGGA,123519,4807.038,N,01131.324,E,1,08,0.9,545.4,M,46.9,M, , *42

123519 = Acquisition du FIX à 12:35:19 UTC
4807.038,N = Latitude 48 deg 07.038' N
01131.324,E = Longitude 11 deg 31.324' E
1 = Fix qualification : (0 = non valide, 1 = Fix GPS, 2 = Fix DGPS)
08 = Nombre de satellites en poursuite.
0.9 = DOP (Horizontal dilution of position) Dilution horizontale.
545.4,M = Altitude, en Mètres, au dessus du MSL (mean see level) niveau moyen des Océans. 46.9,M = Correction de la hauteur de la géoïde en Mètres par rapport à l'ellipsoïde WGS84 (MSL). (Champ vide) = nombre de secondes écoulées depuis la dernière mise à jour DGPS.
(Champ vide) = Identification de la station DGPS.
*42 = Checksum

Non représentés CR et LF.

### 4 - La trame : GLL

Position Géographique - Longitude / Latitude – GPS

### $GPGLL,4916.45,N,12311.12,W,225444,A

4916.46,N = Latitude 49 deg. 16.45 min. Nord. 12311.12,W = Longitude 123 deg. 11.12 min. West (ouest) 225444 = Acquisition du Fix à 22:54:44 UTC
A = Données valides
Pas de checksum

Non représentés CR et LF

### 5 - La Trame : GSA

Satellites actifs - DOP dilution de précision -GPS

### $GPGSA,A,3,04,05,,09,12,,,24,,,,,2.5,1.3,2.1*39

A= Sélection Automatique 2D ou 3D du FIX (M=Manuel)
3 = Fix 3D
04,05... = PRNs (N° d'Id) des satellites utilisés pour le FIX (maximum 12 satellites) 2.5 = PDOP (dilution de précision)
1.3 = Dilution de précision horizontale(HDOP)
2.1 = Dilution de précision verticale (VDOP)
*39 = Checksum

Non représentés CR et LF

Note : La DOP, dilution de précision est une indication de l'effet de la géométrie des satellites sur la précision du Fix.

Les trames NMEA | BAC PRO SEN EIE | LP du Giennois | page : 2

### 6 - La trame : GSV

Satellites en vue - GPS

### $GPGSV,2,1,08,01,40,083,46,02,17,308,41,12,07,344,39,14,22,228,45*75

2 = Nombre de trames GSV avec les données complètes.
1 = Trame 1 de 2 trames (jusqu'à 3 trames)
08 = Nombre de satellites visibles (SV).
01 = N° d'identification du 1er Satellite.
40 = Elévation en degrés du 1er Satellite.
083 = Azimut en degrés du 1er Satellite.
46 = Force du signal du 1er Satellite (Plus grand=meilleur)

(Cette séquence se répète jusqu'à 4 satellites par trames.
On peut donc avoir jusqu'à 3 trames GSV dans une transmission (12 satellites).) *75 = cheksum

non représentés les CR et LF

Ce qui explique la limitation à 12 satellites des GPS grand public.

### 7 -La trame : VTG

Cap (direction) et vitesse sol GPS

### $GPVTG,054.7,T,034.4,M,005.5,N,010.2,K

054.7,T = cap réel en Degrés , T (True track made good)
034.4,M = cap vrai magnétique en Degrés (Magnetic track made good) 005.5,N = Vitesse du déplacement par rapport au sol en Noeuds (N)
010.2,K = Vitesse du déplacement par rapport au sol en Kilomètres heure. (K)

non représentés CR et LF

### 8 - La Trame RMC

Données minimales recommandées de spécification GPS

### $GPRMC,225446,A,4916.45,N,12311.12,W,000.5,054.7,191194,020.3,E*68

225446 = Heure du Fix 22:54:46 UTC
A = Alerte du logiciel de navigation ( A = OK, V = warning (alerte)
4916.45,N = Latitude 49 deg. 16.45 min North
12311.12,W = Longitude 123 deg. 11.12 min West
000.5 = vitesse sol, Noeuds
054.7 = cap (vrai)
191194 = Date du fix 19 Novembre 1994 020.3,E = Déclinaison Magnétique 20.3 deg Est *68 = checksum obligatoire

Non représentés CR et LF

Ces données "minimales", sont le plus souvent utilisées dans les programmes de navigation-GPS simples.

Les trames NMEA | BAC PRO SEN EIE | LP du Giennois | page : 3

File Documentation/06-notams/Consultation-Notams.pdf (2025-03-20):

# Site du Service de l’Information Aéronautique (SIA)

## Consultation des Notams

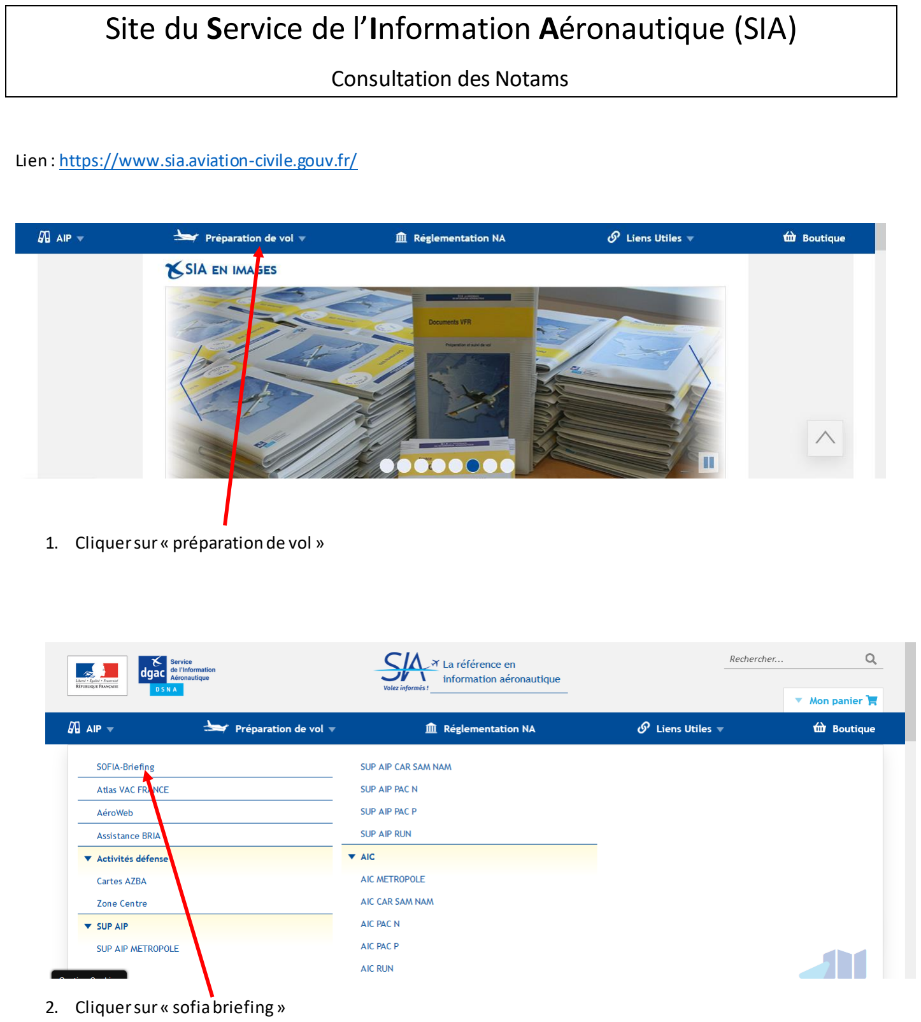
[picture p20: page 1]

Lien : https://www.sia.aviation-civile.gouv.fr/

1. Cliquer sur « préparation de vol »
2. Cliquer sur « sofiabriefing »

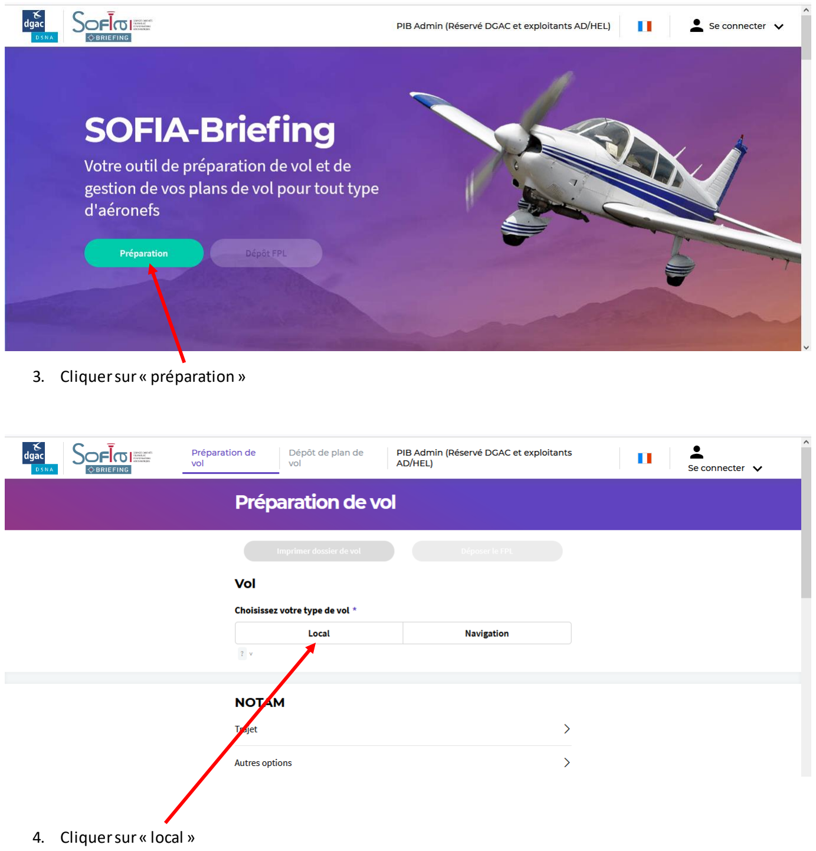
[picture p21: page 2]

3. Cliquer sur « préparation »
4. Cliquer sur « local »

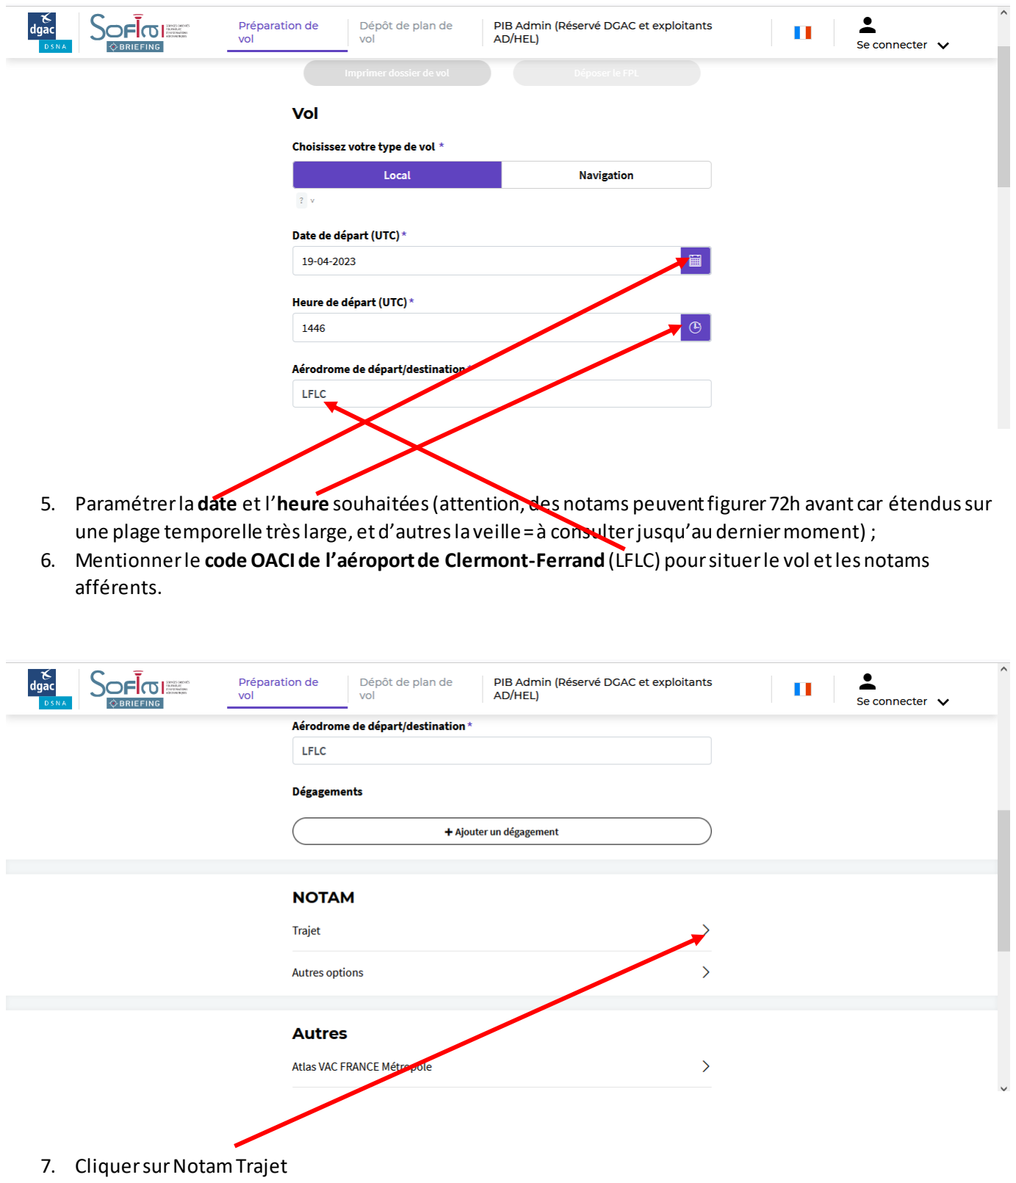
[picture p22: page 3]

5. Paramétrer la date et l’heure souhaitées(attention, des notams peuvent figurer 72h avant car étendus sur une plage temporelle très large, et d’autres la veille = à consulter jusqu’au dernier moment) ;
6. Mentionner le code OACI de l’aéroport de Clermont-Ferrand (LFLC) pour situer le vol et les notams afférents.
7. Cliquer sur Notam Trajet

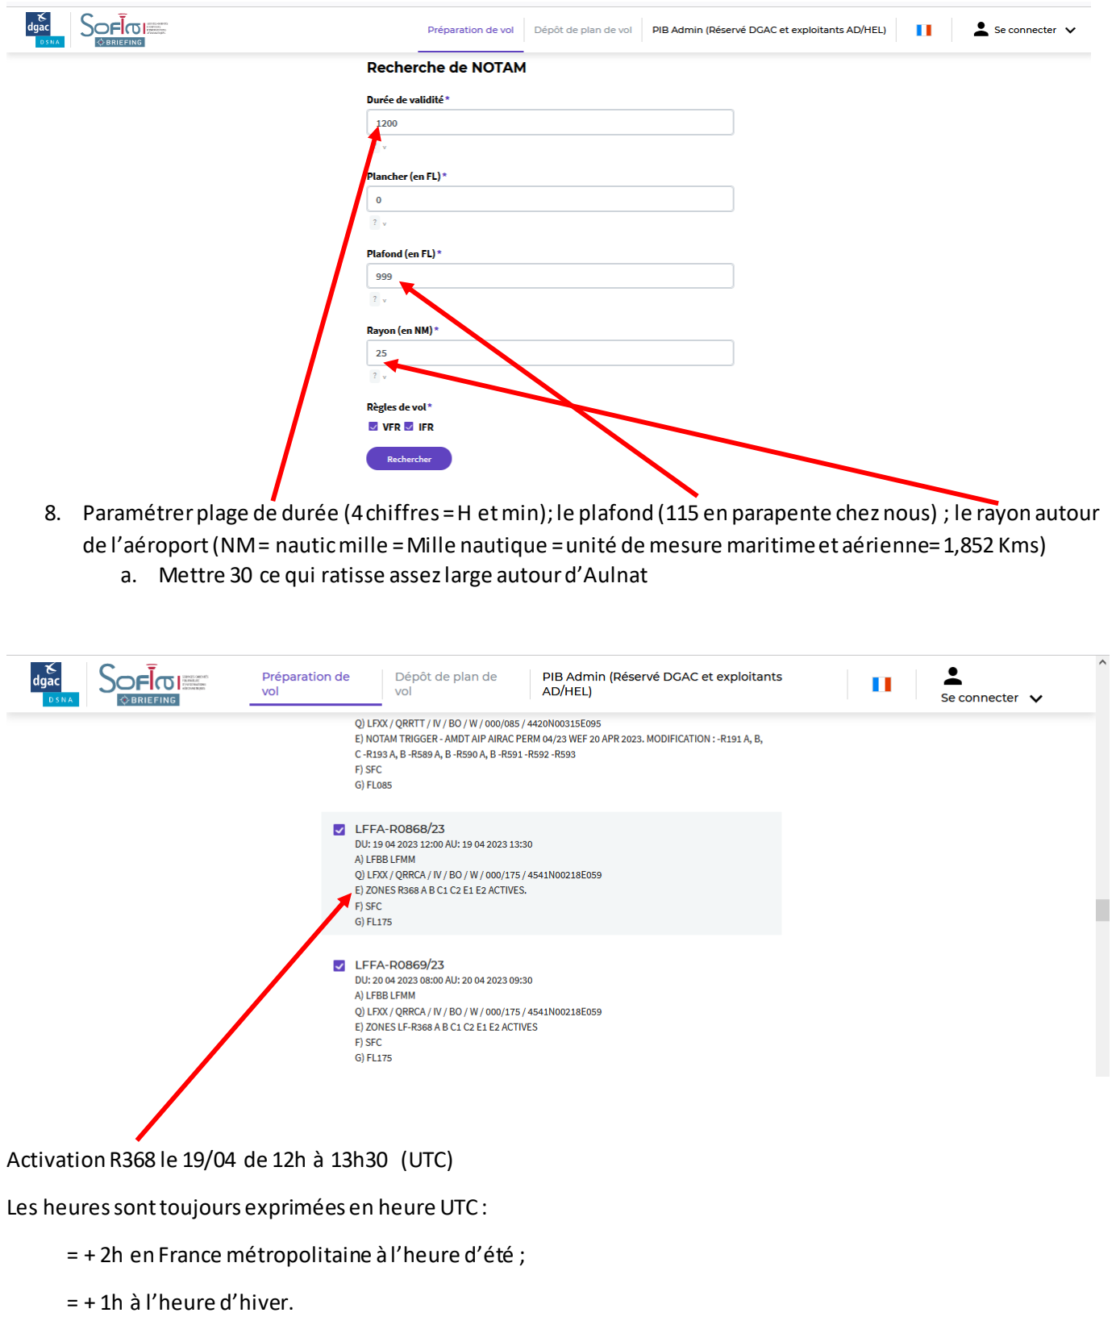
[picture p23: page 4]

8. Paramétrer plage de durée (4 chiffres = H et min); le plafond (115 en parapente chez nous) ; le rayon autour de l’aéroport(NM = nautic mille = Mille nautique = unité de mesure maritime et aérienne= 1,852 Kms)
a. Mettre 30 ce qui ratisse assez large autour d’Aulnat

Activation R368 le 19/04 de 12h à 13h30 (UTC)

Les heures sont toujours exprimées en heure UTC :

= + 2h en France métropolitaine à l’heure d’été ;

= + 1h à l’heure d’hiver.

## Décrypter un NOTAM

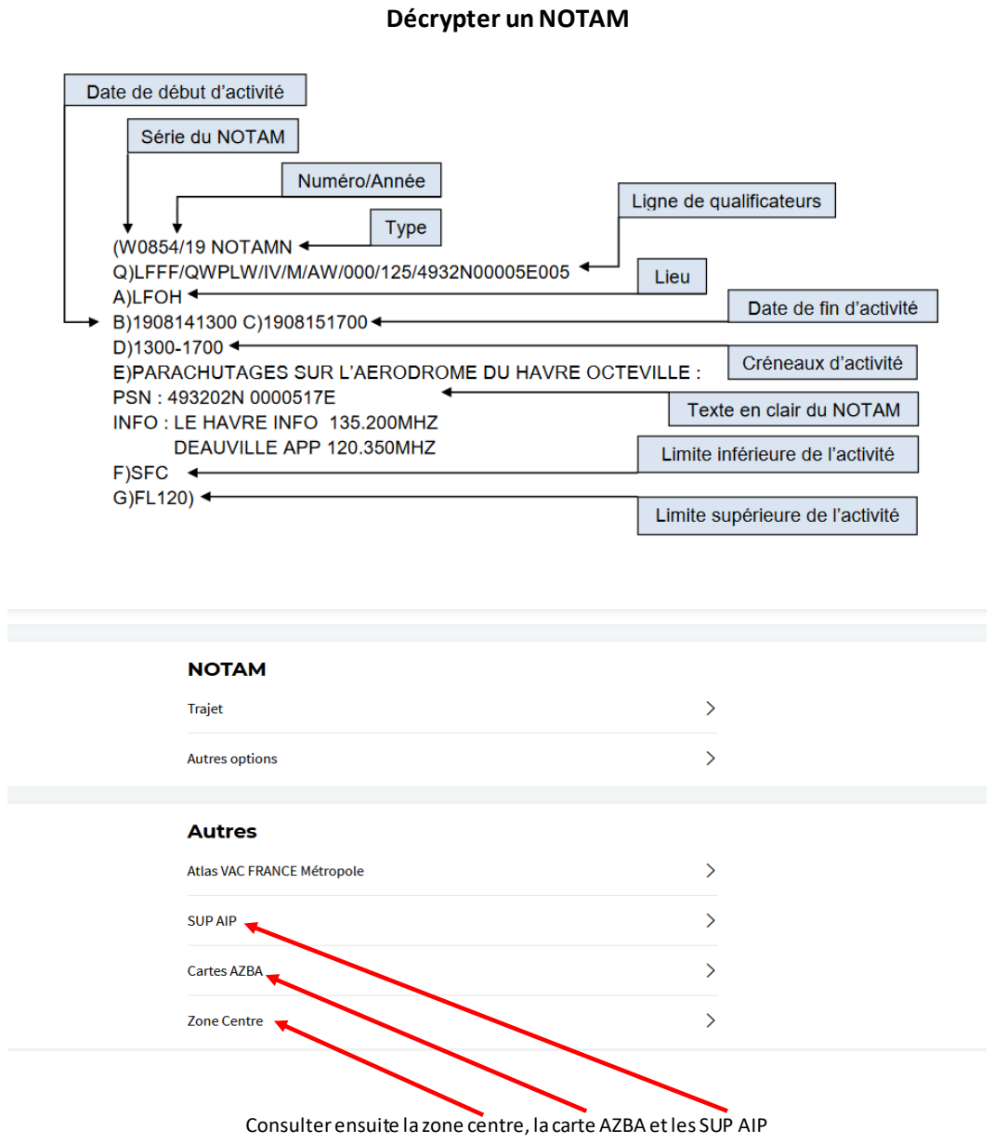
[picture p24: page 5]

Consulter ensuite la zone centre, la carte AZBA et les SUP AIP

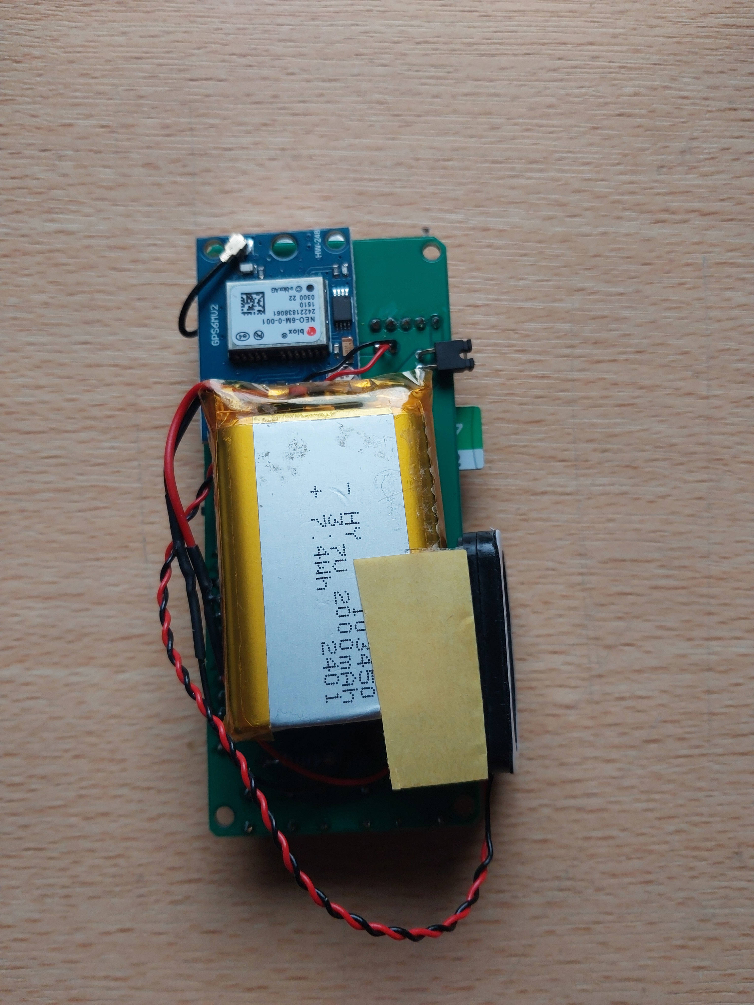
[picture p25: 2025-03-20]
Photos/08-bv213-sans-boitier-2.jpg

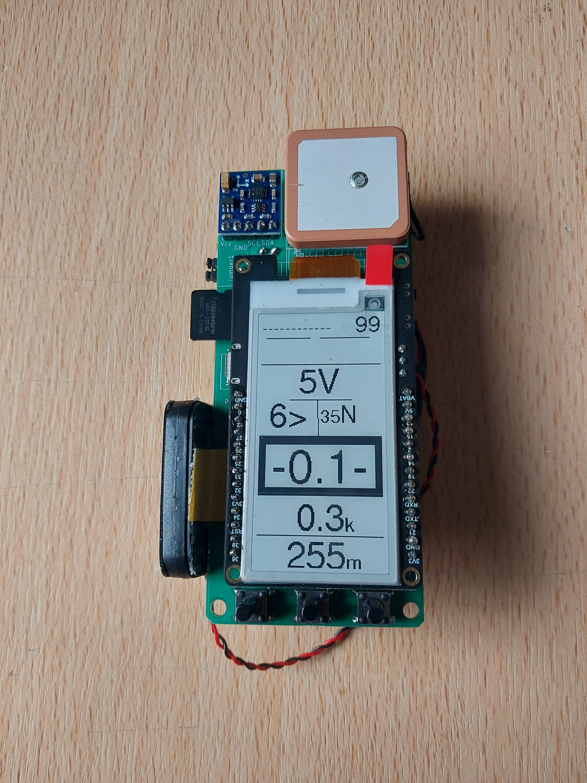
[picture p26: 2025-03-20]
Photos/07-bv213-sans-boitier-1.jpg

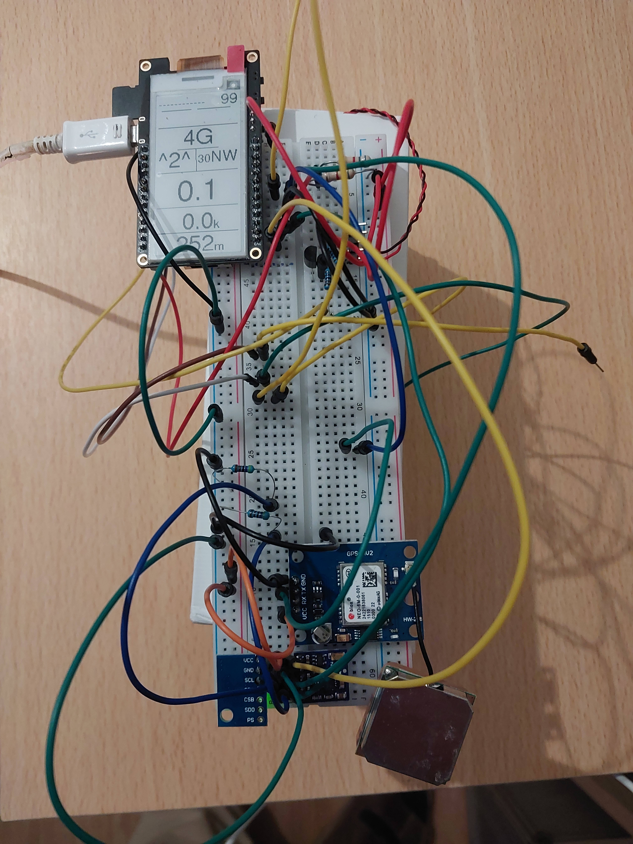
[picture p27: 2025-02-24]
Photos/03-cablage.jpg

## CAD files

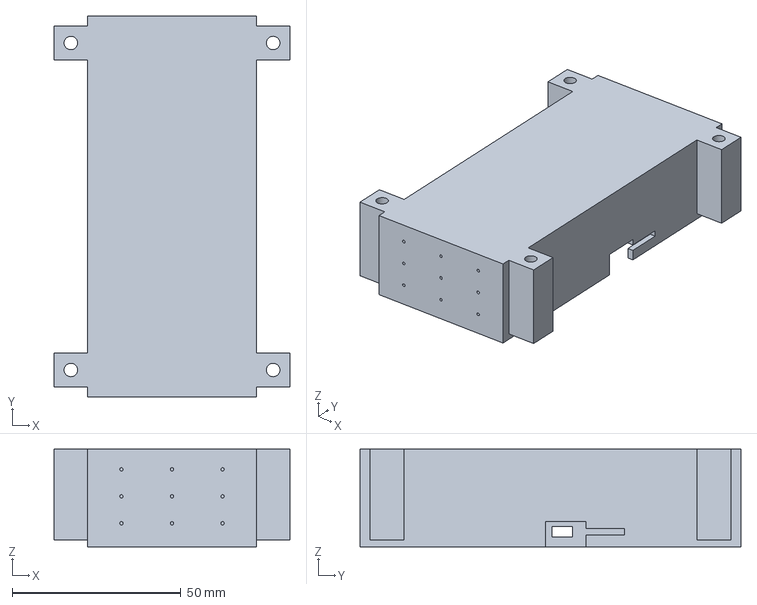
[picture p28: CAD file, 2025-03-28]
FreeCad/BertheVario213-bas.FCStd
70.0 x 113.0 x 29.0 mm

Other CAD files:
FreeCad/carte-esp32/T5_V2.3_2.13.FCStd

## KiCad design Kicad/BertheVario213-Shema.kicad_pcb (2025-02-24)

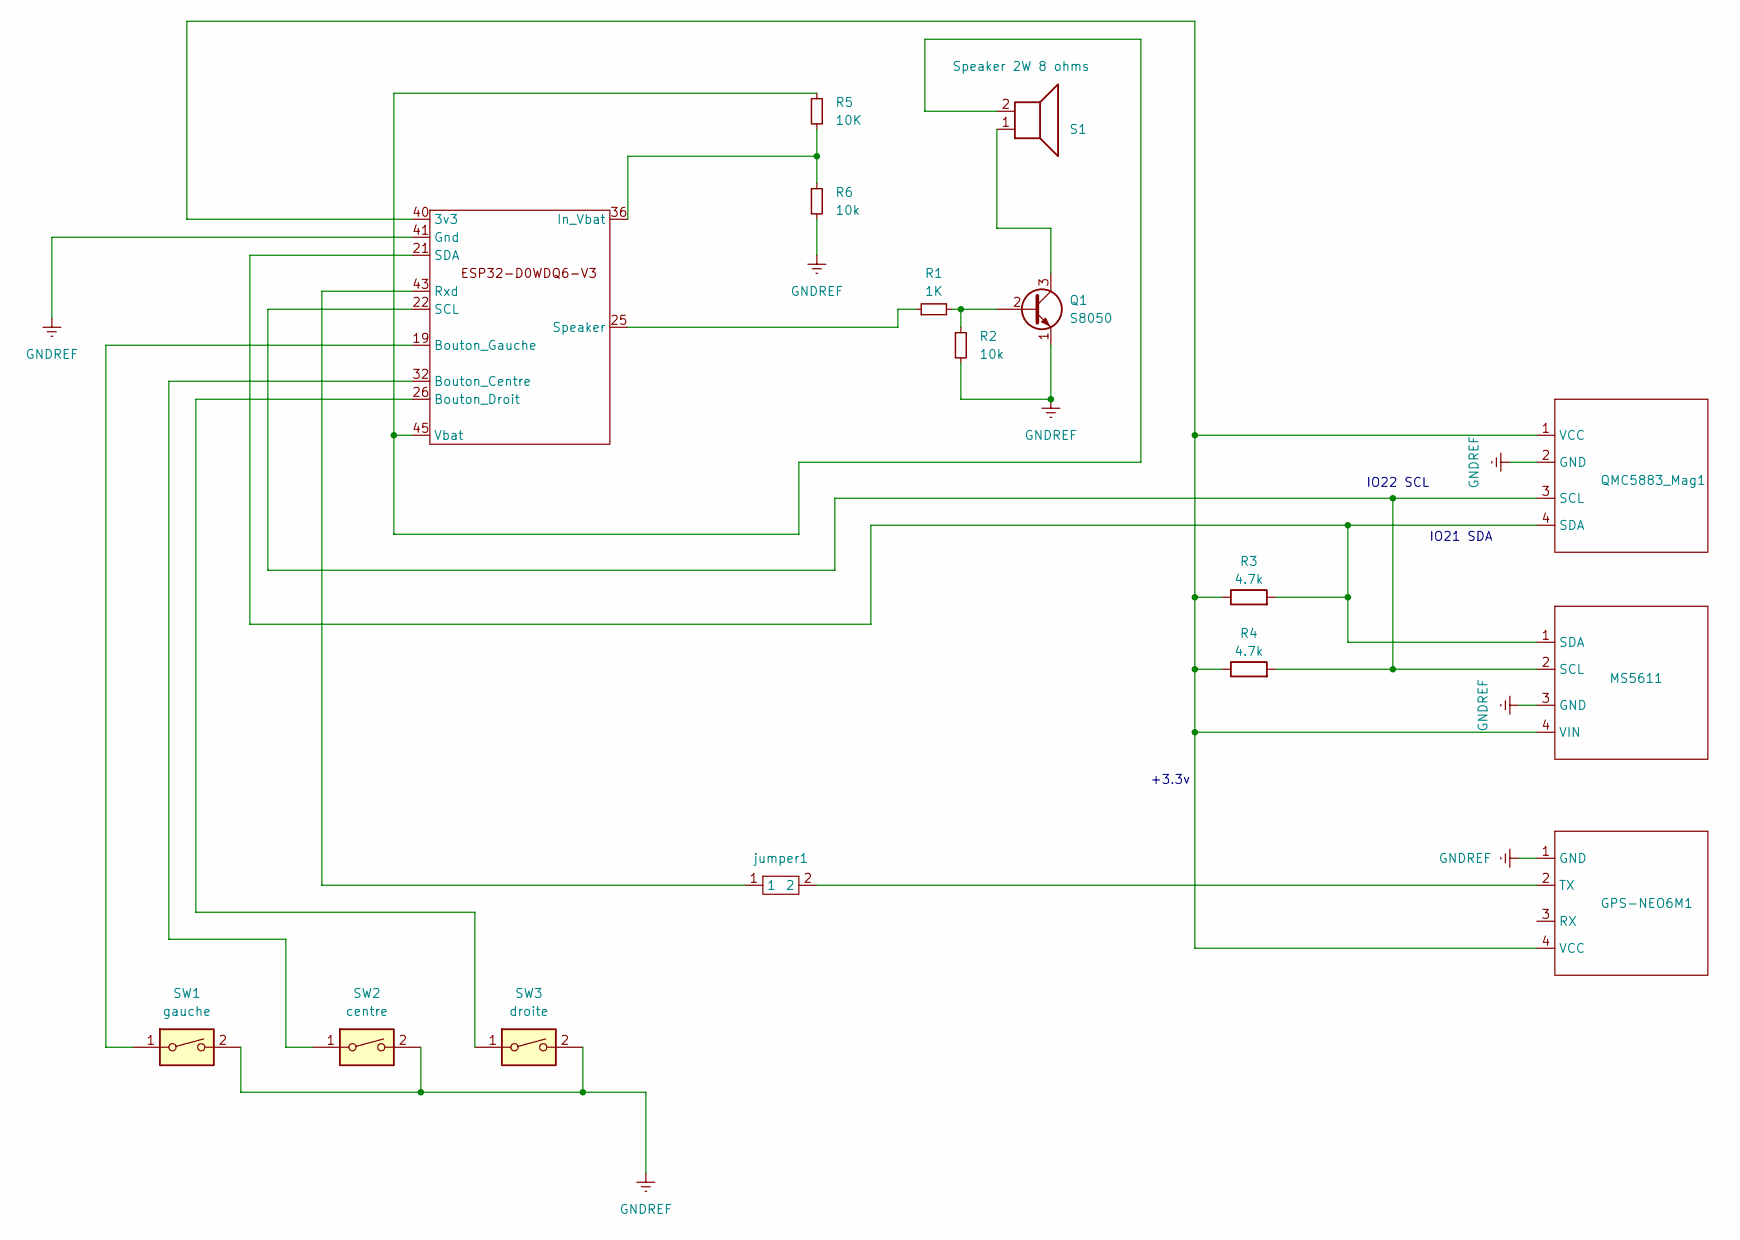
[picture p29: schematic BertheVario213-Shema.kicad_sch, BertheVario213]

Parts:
GPS-NEO6M1: -; GPSNEO6V2
MS5611: MS5611
Q1: S8050
QMC5883_Mag1: QMC5883
R1: 1K; R_47
R2, R6: 10k; R_47
R3, R4: 4.7k; R_47
R5: 10K; R_47
S1: Speaker 2W 8 ohms; 2 trous standard
SW1: gauche; switch
SW2: centre; switch
SW3: droite; switch
U1: ESP32-D0WDQ6
jumper1: jumper

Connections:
GNDREF: GPS-NEO6M1.1 (GND), MS5611.3 (GND), Q1.1 (E), QMC5883_Mag1.2 (GND), R2.2, R6.2, SW1.2, SW2.2, SW3.2, U1.41 (Gnd)
unnamed: GPS-NEO6M1.2 (TX), jumper1.2
unnamed: GPS-NEO6M1.4 (VCC), MS5611.4 (VIN), QMC5883_Mag1.1 (VCC), R3.1, R4.1, U1.40 (3v3)
unnamed: MS5611.2 (SCL), QMC5883_Mag1.3 (SCL), R4.2, U1.22 (SCL)
unnamed: MS5611.1 (SDA), QMC5883_Mag1.4 (SDA), R3.2, U1.21 (SDA)
unnamed: Q1.2 (B), R1.2, R2.1
unnamed: Q1.3 (C), S1.1
unnamed: SW2.1, U1.32 (Bouton_Centre)
unnamed: SW3.1, U1.26 (Bouton_Droit)
unnamed: SW1.1, U1.19 (Bouton_Gauche)
unnamed: R5.2, R6.1, U1.36 (In_Vbat)
unnamed: U1.43 (Rxd), jumper1.1
unnamed: R1.1, U1.25 (Speaker)
unnamed: R5.1, S1.2, U1.45 (Vbat)

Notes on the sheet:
IO22 SCL
IO21 SDA
+3.3v

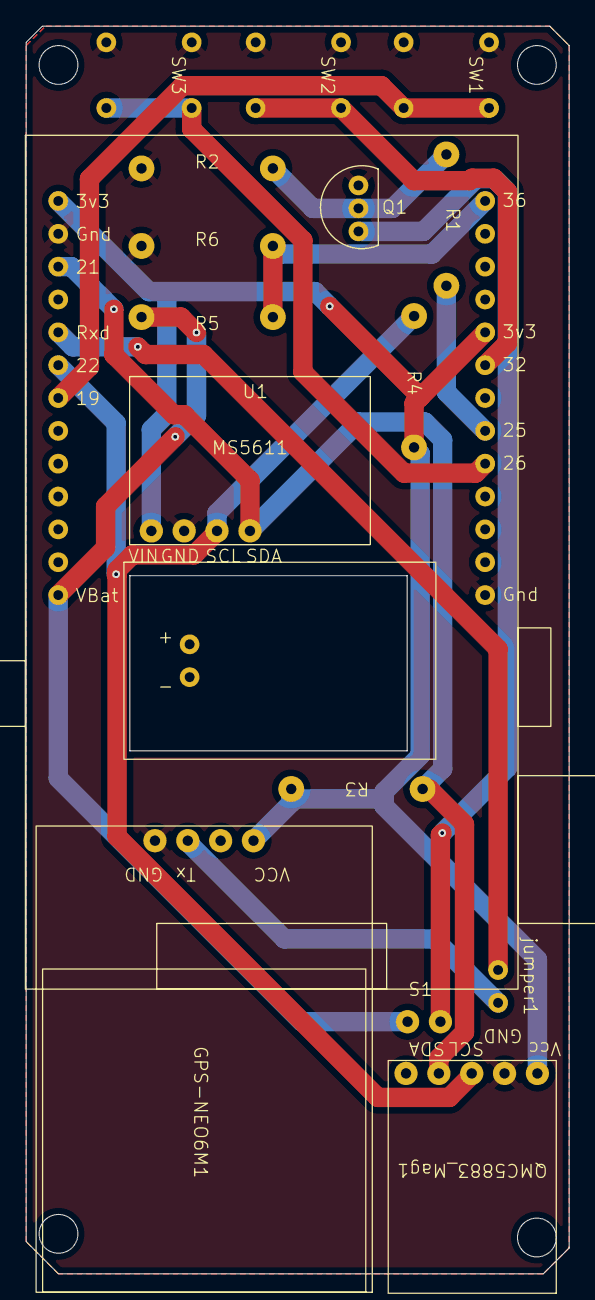
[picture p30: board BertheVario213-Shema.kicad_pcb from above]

Board: 2 copper layers, 42.0 x 96.5 mm, 16 parts (0 on the bottom side), 14 nets.

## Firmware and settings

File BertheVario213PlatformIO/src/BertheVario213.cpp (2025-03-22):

////////////////////////////////////////////////////////////////////////////////
/// \file BerheVario.cpp
///
/// \brief Fichier principal du projet GNU-Vario de Berthe
///
/// \date creation     : 02/03/2024
/// \date modification : 22/03/2025
///

char NumVer[] = "20250322b" ;

// uncomment next line to use HSPI for EPD (and e.g VSPI for SD), e.g. with Waveshare ESP32 Driver Board
//#define USE_HSPI_FOR_EPD

#include "BertheVario213.h"

// variable globale du programme
CGlobalVar g_GlobalVar ;

// note for partial update window and setPartialWindow() method:
// partial update window size and position is on byte boundary in physical x direction
// the size is increased in setPartialWindow() if x or w are not multiple of 8 for even rotation, y or h for odd rotation
// see also comment in GxEPD2_BW.h, GxEPD2_3C.h or GxEPD2_GFX.h for method setPartialWindow()

//VarioBle VBle ;

///////////////////////////////////////////////////////////////////////////////
/// \brief fonction setup de demmarrage.
void setup()
{
//VBle.init( "BerteVario" ) ;

// init port serie de console
Serial.begin(115200);
Serial.println("Setup") ;
#ifdef G_DEBUG
 Serial.println();
 Serial.println("fonction setup");
 delay(100);
#endif

// beeper init
g_GlobalVar.LanceTacheSound() ;
delay( 300 ) ;
CGlobalVar::BeepOk() ;

// init ecran
g_GlobalVar.InitScreen() ;

// pour la lecture de la batterie
g_GlobalVar.InitAlim() ;

// affichage boutons
g_GlobalVar.AfficheBoutons() ;

// init boutons
g_GlobalVar.InitButton() ;

// init sdcard
g_GlobalVar.InitSDCard() ;

// boutons
bool BoutonGaucheAppuye = false ;  // calibration
bool BoutonCentreAppuye = false ;  // mode wifi
bool BoutonDroitAppuye = false ;   // mode rando-vol
unsigned long time = millis() ;
while ( (millis() - time) < 400 )
    {
    if ( g_GlobalVar.BoutonDroit() )
        BoutonDroitAppuye = true ;
    if ( g_GlobalVar.BoutonGauche() )
        BoutonGaucheAppuye = true ;
    if ( g_GlobalVar.BoutonCentre() )
        BoutonCentreAppuye = true ;
    }
g_GlobalVar.BootEffectue() ;

// affichage voltage
g_GlobalVar.AfficheVoltage() ;


// si un bouton appuye
if ( BoutonCentreAppuye || BoutonDroitAppuye || BoutonGaucheAppuye )
    {
    // lecture fichier de configuration
    g_GlobalVar.m_Config.LectureFichier() ;

    // lecture fichier zones aeriennes
    if ( BoutonCentreAppuye )
        g_GlobalVar.m_ZonesAerAll.LectureFichiers() ;
    }
else
    {
    // lecture fichier de configuration
    g_GlobalVar.m_Config.LectureFichier() ;

    // lecture fichier terrains
    g_GlobalVar.m_TerrainArr.LireFichierTerrains(TERRAIN_FCH) ;

    // lecture fichier zones aeriennes
    g_GlobalVar.m_ZonesAerAll.LectureFichiers() ;
    }


// Init BUS I2C
g_GlobalVar.InitI2C() ;

////////////////////
// si mode http wifi
if ( BoutonCentreAppuye )
    {
    g_GlobalVar.m_Config.LectureFichier() ;

    #ifdef XC_TRACK
     // desactive ble
     esp_bt_controller_disable();
     esp_bt_controller_deinit();
    #endif

    // mode ftp pour loop
    g_GlobalVar.m_ModeHttp = true ;

    // creation fichier de validation zones
    g_GlobalVar.m_ZonesAerAll.Valid() ;
    // liberation memoire
    g_GlobalVar.m_ZonesAerAll.DeleteAll() ;

    // affichage
    g_GlobalVar.AfficheConnectWifi() ;

    // connection wifi
    WiFi.begin( g_GlobalVar.m_Config.m_Ssid.c_str(), g_GlobalVar.m_Config.m_Passwd.c_str() );
    while (WiFi.status() != WL_CONNECTED)
        {
        delay(500);
        Serial.print(".");
        }

    #ifdef HTTP_DEBUG
    Serial.println("");
    Serial.print("Connected to ");
    Serial.println(WIFI_SSID);
    Serial.print("IP address: ");
    Serial.println(WiFi.localIP());
    #endif

    // adresse wifi
    char buf[50];
    sprintf(buf, "%d.%d.%d.%d", WiFi.localIP()[0], WiFi.localIP()[1], WiFi.localIP()[2], WiFi.localIP()[3] );
    g_GlobalVar.AfficheWifi( buf ) ;

    // creation init file manager
    pfilemgr = new ESPFMfGK( 8080 ) ;

    addFileSystems();
    setupFilemanager();

    return ;
    }
else
    g_GlobalVar.m_ModeHttp = false ;

// capteur de pression temperature
g_GlobalVar.m_MS5611Press.InitMs5611() ;

// capteur accelerometrique/cap magnetique
g_GlobalVar.m_QMC5883Mag.InitMagnetique() ;

// init port serie GPS
g_GlobalVar.InitGps() ;

////////////////////////////////////
// si calibration capteur magnetique
if ( BoutonGaucheAppuye )
    {
    g_GlobalVar.AfficheCalibreMag() ;
    g_GlobalVar.m_QMC5883Mag.CalibrationMagnetique() ;
    CGlobalVar::Reboot() ;
    }

// lancement tache de calcul de la Vz et acquisition cap magnetique
g_GlobalVar.m_MS5611Press.LancerTacheCalculVzCapMag() ;

/////////////////////
// si mode vol-rando
#ifdef DEBUG_RANDO_VOl
 g_GlobalVar.m_ModeRandoVol = true ;
 return ;
#endif
if ( BoutonDroitAppuye )
    {
    #ifdef XC_TRACK
     // desactive ble
     esp_bt_controller_disable();
     esp_bt_controller_deinit();
    #endif

    g_GlobalVar.m_Config.LectureFichier() ;
    g_GlobalVar.m_ModeRandoVol = true ;
    return ;
    }
else
    g_GlobalVar.m_ModeRandoVol = false ;

// lancement tache gps
g_GlobalVar.LanceTacheGps(true) ;

// lancement tache beep
g_GlobalVar.LanceTacheVarioBeep() ;

// screen tache de fond calcul
g_GlobalVar.LancerTacheCalcul() ;

// tache de mesure % utilisation cpu
perfmon_start() ;

#ifdef XC_TRACK
// blue tooth
    g_GlobalVar.m_BleXct.Init( BLE_NAME ) ;
//#else
//    esp_bt_controller_disable();
//    esp_bt_controller_deinit();
#endif

#ifdef G_DEBUG
  Serial.println("setup done");
#endif
}

bool once = true ;
bool once_ota = true ;

/* AsyncClient* client = new AsyncClient;
#define HOST "pdd.dprslt.fr"
#define PORT 80 */

///////////////////////////////////////////////////////////////////////////////
/// \brief fonction loop toujours appelée.
void loop()
{
/*
//client->write("GET /README.md HTTP/1.1\r\nHost: " HOST "\r\nUser-Agent: ESP\r\nConnection: close\r\n\r\n");
  client->onError([](void* arg, AsyncClient* client, int8_t error) {
    Serial.printf("** error occurred %s \n", client->errorToString(error));
    client->close(true);
    //delete client;
  });

  client->onDisconnect([](void* arg, AsyncClient* client) {
      Serial.printf("** client has been disconnected: %" PRIu16 "\n", client->localPort());
      //client->close(true);
      //delete client;

      //permits++;
      //makeRequest();
    });

    client->onData([](void* arg, AsyncClient* client, void* data, size_t len) {
      //Serial.printf("** data received by client: %" PRIu16 ": len=%u\n", client->localPort(), len);
      Serial.printf( (char*)data) ;
    });

  client->onConnect([](void* arg, AsyncClient* client) {
    //pekhoih-prog/AsyncTCP_SSL@^1.3.1
	armmbed/mbedtls@^2.23.0rmits--;
    Serial.printf("** client has been connected: %" PRIu16 "\n", client->localPort());

    //client->connect(HOST,client->localPort());

    //client->write("GET /README.md HTTP/1.1\r\nHost: " HOST "\r\nUser-Agent: ESP\r\nConnection: close\r\n\r\n");
    client->write("GET /space/notams HTTP/1.0\r\nHost: " HOST "\r\nUser-Agent: ESP\r\nConnection: open\n\r\n");
    }) ;

  if (once && client->connect(HOST, PORT))
    {
    once = false ;
    Serial.println( "connect ok" ) ;
    }
  //else
  //    client->write("GET /README.md HTTP/1.1\r\nHost: " HOST "\r\nUser-Agent: ESP\r\nConnection: close\r\n\r\n");

return ;
*/

/*g_GlobalVar.m_VitVertMS += 0.1 ;
if ( g_GlobalVar.m_VitVertMS >= 0.3 )
    g_GlobalVar.m_VitVertMS *= -1 ;*/


// si boucle a ne plus faire
if ( g_GlobalVar.m_StopLoop )
    {
    delay( 100 ) ;
    return ;
    }

////////////////////
// si mode http wifi
if ( g_GlobalVar.m_ModeHttp )
    {
    pfilemgr->handleClient();
    return ;
    }

////////////////////
// si mode rando-vol
if ( g_GlobalVar.m_ModeRandoVol )
    {
    if ( once )
        {
        once = false ;
        g_GlobalVar.InitRandoVol() ;
        }
    g_GlobalVar.AfficheRandoVol() ;
    delay( 200 ) ;
    return ;
    }

//////////////////////////////////
// si mode telechargement firmware
if ( g_GlobalVar.m_ModeHttpOta )
    {
    if ( once_ota )
        {
        once_ota = false ;
        WifiInitOta() ;
        return ;
        }

    WifiOtaHandle() ;

    return ;
    }

// bip demarrage premiere boucle
if ( once )
    {
    once = false ;
    CGlobalVar::BeepOk() ;
    CGlobalVar::beeper( SOUND_DELAY_ONLY , 200 );
    CGlobalVar::BeepOk() ;

    // puy de dome pour test fichier hgt
    float Lat = 45.772396 ;
    float Lon = 2.964061  ;
    //Lon = 0 ;  Lat = 39 ; // pour test
    g_GlobalVar.m_Hgt2Agl.GetGroundZ( Lon , Lat ) ;

    // simu vol
    #ifdef SIMU_VOL
     g_SimuVol.LancerTacheSimuVol() ;
    #endif
    }

// message de debugage
#ifdef G_DEBUG
 Serial.println("fonction loop");
#endif

// fonction d'affichage
//unsigned long TimeAvAff = millis() ;
g_GlobalVar.AfficheAll();

// attente 0.5s, l'affichage n'est pas prioritaire
//while ( (millis() - TimeAvAff) < 500 )
//    delay( 10 ) ;

/*
// pression hPascal, altitude meters ,vario cm/s, temperature C, battery voltage, *checksum
char Sentence[500] ;
sprintf( Sentence , "LK8EX1,999999,%f,99,99,999",g_GlobalVar.m_TerrainPosCur.m_AltiBaro ) ;
int Len = strlen( Sentence ) ;
unsigned int checksum , ai, bi;                                               // Calculating checksum for data string
for (checksum = 0, ai = 0; ai < Len ; ai++)
    {
    bi = (unsigned char)Sentence[ai];
    checksum ^= bi;
    }

char Sentence2[500] ; // = "$LK8EX1,98974,197,0,99,999*32\r\n" ;
sprintf( Sentence2 , "$%s*%X\r\n" , Sentence , checksum ) ;
int Len2 = strlen( Sentence2 ) ;
for ( int ic = 0 ; ic < Len2 ; ic++ )
    VBle.write( Sentence2[ic] ) ;
VBle.flush() ;
*/
}

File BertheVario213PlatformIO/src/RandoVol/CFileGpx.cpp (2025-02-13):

////////////////////////////////////////////////////////////////////////////////
/// \file CFileGpx.cpp
///
/// \brief
///
/// \date creation     : 14/01/2025
/// \date modification : 18/01/2025
///

#include "../BertheVario213.h"

////////////////////////////////////////////////////////////////////////////////
/// \brief
CFileGpx::~CFileGpx()
{
if ( m_pVecTrack != NULL )
    delete m_pVecTrack ;
}

////////////////////////////////////////////////////////////////////////////////
/// \brief lit un fichier et remplit la trace
void CFileGpx::LireFichier(bool AvecAlt)
{
char TmpChar[1000] = "" ;

// raz precedent
m_TrackName = "" ;

// ouverture fichier
File file = SD.open(m_FileName.c_str());
if ( !file )
    {
    Serial.println("Failed to open file for reading");
    return;
    }

if ( m_pVecTrack == NULL )
    m_pVecTrack = new std::vector<StPoint> ;
else
    m_pVecTrack->clear() ;
m_pVecTrack->reserve( 100 ) ;

// lecture fichier
int ic = 0 ;
while(file.available())
    {
    char c = file.read() ;
    TmpChar[ic++] = c ;
    if ( c == '\n' )
        {
        TmpChar[ic++] = 0 ;
        ic = 0 ;
        TraiteLigne( TmpChar , AvecAlt ) ;
        }
    }
TmpChar[ic++] = 0 ;
TraiteLigne( TmpChar , AvecAlt ) ;

// fermeture fichier
file.close() ;

m_pVecTrack->shrink_to_fit() ;
}

////////////////////////////////////////////////////////////////////////////////
/// \brief Calcul de la loupe de depart et de la distance minimale a un point de
/// la trace.
void CFileGpx::SetDistanceFrom( const StPoint PtCur )
{
m_DistFrom = 500.*500. ;
float DeltaLL = 0 ;

m_Barycenter.m_Lat = 0 ;
m_Barycenter.m_Lon = 0 ;
for ( int i = 0 ; i < m_pVecTrack->size() ; i++ )
    {
    m_Barycenter.m_Lat += (*m_pVecTrack)[i].m_Lat ;
    m_Barycenter.m_Lon += (*m_pVecTrack)[i].m_Lon ;

    float DistFrom = sqrtf( powf(PtCur.m_Lat-(*m_pVecTrack)[i].m_Lat,2.0) + powf(PtCur.m_Lon-(*m_pVecTrack)[i].m_Lon,2.0) ) ;
    if ( m_DistFrom > DistFrom )
        m_DistFrom = DistFrom ;
    }
m_Barycenter.m_Lat /= m_pVecTrack->size() ;
m_Barycenter.m_Lon /= m_pVecTrack->size() ;

// delta de lat/lon
for ( int i = 0 ; i < (*m_pVecTrack).size() ; i++ )
    {
    float Dist = fabsf(m_Barycenter.m_Lat - (*m_pVecTrack)[i].m_Lat) ;
    if ( DeltaLL < Dist )
        DeltaLL = Dist ;
    Dist = fabsf(m_Barycenter.m_Lon - (*m_pVecTrack)[i].m_Lon) ;
    if ( DeltaLL < Dist )
        DeltaLL = Dist ;
    }
m_SlopeMax = 3.*DeltaLL/SLOPE_MAX_DIV ;
}

////////////////////////////////////////////////////////////////////////////////
/// \brief Traite une ligne de *.gpx
void CFileGpx::TraiteLigne( char * Ligne , bool AvecAlt )
{
// nom piste
if ( m_TrackName == "" && strstr( Ligne , "<name>" ) != NULL )
    {
    strtok( Ligne , "<>" ) ;
    strtok( NULL , "<>" ) ;
    m_TrackName = strtok( NULL , "<>" ) ;
    }
// point de piste
else if ( strstr( Ligne , "<trkpt " ) != NULL )
    {
    StPoint Pts ;
    strtok( Ligne , "\"" ) ;
    Pts.m_Lat = atof( strtok( NULL , "\"" ) ) ;
    strtok( NULL , "\"" ) ;
    Pts.m_Lon = atof( strtok( NULL , "\"" ) ) ;
    m_pVecTrack->push_back( Pts ) ;
    //Serial.print( Pts.m_Lat ) ;
    //Serial.print( " " ) ;
    //Serial.println( Pts.m_Lon ) ;
    }
// altitude du dernier point
else if ( AvecAlt && strstr( Ligne , "<ele>" ) != NULL && m_pVecTrack->size() )
    {
    StPoint & Pts = (*m_pVecTrack)[m_pVecTrack->size()-1] ;
    strtok( Ligne , "<>" ) ;
    strtok( NULL , "<>" ) ;
    Pts.m_Alt = atof( strtok( NULL , "<>" ) ) ;
    //Serial.println( Pts.m_Alt ) ;
    }
}

////////////////////////////////////////////////////////////////////////////////
/// \brief Renvoie la distance et l'altitude restante en metres.
void CFileGpx::GetInfo( const StPoint PtCur , float & AltitudeRest , float & DistanceRest , float & AltitudeFait , float & DistanceFait )
{
// determination du pt proche
int iPtProche = 0 ;
float DistProche = 360. ;
for ( int i = 0 ; i < m_pVecTrack->size() ; i++ )
    {
    float Dist = powf(PtCur.m_Lat-(*m_pVecTrack)[i].m_Lat,2.0) + powf(PtCur.m_Lon-(*m_pVecTrack)[i].m_Lon,2.0) ;
    if ( DistProche > Dist )
        {
        DistProche = Dist ;
        iPtProche = i ;
        }
    }

// init altitude distance restante
DistanceRest = DistanceMetre( PtCur , (*m_pVecTrack)[iPtProche] ) ;
AltitudeRest = (*m_pVecTrack)[iPtProche].m_Alt - PtCur.m_Alt ;
if ( AltitudeRest < 0 )
    AltitudeRest = 0 ;
for ( int i = iPtProche + 1 ; i < m_pVecTrack->size() ; i++ )
    {
    DistanceRest += DistanceMetre( (*m_pVecTrack)[i-1] , (*m_pVecTrack)[i] ) ;
    float AltiPos = (*m_pVecTrack)[i].m_Alt - (*m_pVecTrack)[i-1].m_Alt ;
    if ( AltiPos > 0. )
        AltitudeRest += AltiPos ;
    }

// init altitude distance fait
DistanceFait = DistanceMetre( PtCur , (*m_pVecTrack)[iPtProche] ) ;
AltitudeFait = PtCur.m_Alt - (*m_pVecTrack)[iPtProche].m_Alt ;
if ( AltitudeFait < 0 )
    AltitudeFait = 0 ;
for ( int i = 0 ; i < iPtProche && i < m_pVecTrack->size() ; i++ )
    {
    DistanceFait += DistanceMetre( (*m_pVecTrack)[i+1] , (*m_pVecTrack)[i] ) ;
    float AltiPos = (*m_pVecTrack)[i+1].m_Alt - (*m_pVecTrack)[i].m_Alt ;
    if ( AltiPos > 0. )
        AltitudeFait += AltiPos ;
    }
}

////////////////////////////////////////////////////////////////////////////////
/// \brief Renvoie la distance entre points en metres
float CFileGpx::DistanceMetre( StPoint PtA , StPoint PtB ) const
{
float DelLat = PtA.m_Lat-PtB.m_Lat ;
float DelLon = PtA.m_Lon-PtB.m_Lon ;
float DelAlt = PtA.m_Alt-PtB.m_Alt ;
float Dist = powf(DelLat*MilesParDegres*UnMileEnMetres,2.) + powf(DelLon*MilesParDegres*UnMileEnMetres,2.) + powf(DelAlt,2.) ;
return sqrtf(Dist) ;
}

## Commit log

2025-02-08 complement doc esp32
2025-02-13 tests carte
    [config.txt]
2025-02-15 FreeCad Kicad
    [BertheVario213-Shema.kicad_pcb, BertheVario213-Shema.kicad_sch]
2025-02-15 pcb Kicad
    [BertheVario213-Shema.kicad_pcb, BertheVario213-Shema.kicad_sch]
2025-02-15 empreintes Kicad
    [BertheVario213-Shema.kicad_pcb]
2025-02-16 progession pcb
    [BertheVario213-Shema.kicad_pcb, BertheVario213-Shema.kicad_sch]
2025-02-16 progression pcb
    [BertheVario213-Shema.kicad_sch]
2025-02-16 doc concepteur
    [BertheVario213-Shema.kicad_sch]
2025-02-16 mise a jour kicad
    [BertheVario213-Shema.kicad_sch]
2025-02-16 son vbat
    [BertheVario213-Shema.kicad_sch]
2025-02-16 modif pcb
    [BertheVario213-Shema.kicad_pcb]
2025-02-17 capteurs presssion/magnetique
2025-02-19 schema electrique
    [BertheVario213-Shema.kicad_sch]
2025-02-21 pcb pb
    [BertheVario213-Shema.kicad_pcb, BertheVario213-Shema.kicad_sch]
2025-02-21 pcb a verifier
    [BertheVario213-Shema.kicad_pcb, BertheVario213-Shema.kicad_sch]
2025-02-22 gps pb
    [BertheVario213-Shema.kicad_pcb, BertheVario213-Shema.kicad_sch]
2025-02-24 pcb ok a verifier
    [BertheVario213-Shema.kicad_pcb, BertheVario213-Shema.kicad_sch]
2025-02-25 pcb en production
    [BertheVario213-Shema-B_Cu.gbr, BertheVario213-Shema-B_Mask.gbr, BertheVario213-Shema-B_Paste.gbr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]
2025-02-25 bug periode tma st-yan
    [BertheVario213.cpp, CZonesAerAll.cpp]
2025-03-02 fichiers de zone
2025-03-19 pcb BV-213 ok
2025-03-20 ota bug gps mag
    [BertheVario213.cpp, BertheVario213.h, CBoutons.cpp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]
2025-03-20 page de presentation
2025-03-20 gps magnetique
2025-03-21 freecad esp32
    [T5_V2.3_2.13.FCStd, T5_V2.3_2.13.dxf]
2025-03-21 freecad bas
    [BertheVario213-bas.FCStd]
2025-03-22 base boitier
    [BertheVario213-bas.FCStd]
